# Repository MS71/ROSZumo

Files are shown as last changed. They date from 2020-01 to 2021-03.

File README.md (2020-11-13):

# ROSZumo
"second" Small robot based on ESP32 + ROS + ZUMO 32u4 base

Components:
* ZUMO32U4 Base (I2C Slave, Bat ADC, Motor Encoder, PWM for Lidar Stepper, l3gd20h, lsm303d, Line Sonsor, ...)
* ESP32CAM
* ESP32 WRoverwith CAM and SDCard
* driver and connector for rotating LIDAR
* 12x STM VL53L1X TOF sensor
* optional rotating Lidar with PCF8475+ULN2003 Stepper motor
* BNO055 Orientation Sensor
* STM32G081 uC
* connector for orange PI Zero H5
* connector for RPI SPI Display
* NIMH charger with front contacts
* SPI flash
* I2C level shifter
* I2C bus connector
* SPI bus connector
* low power design (shutdown and wakeup)
* optional Stereo/Quad SPI Camera

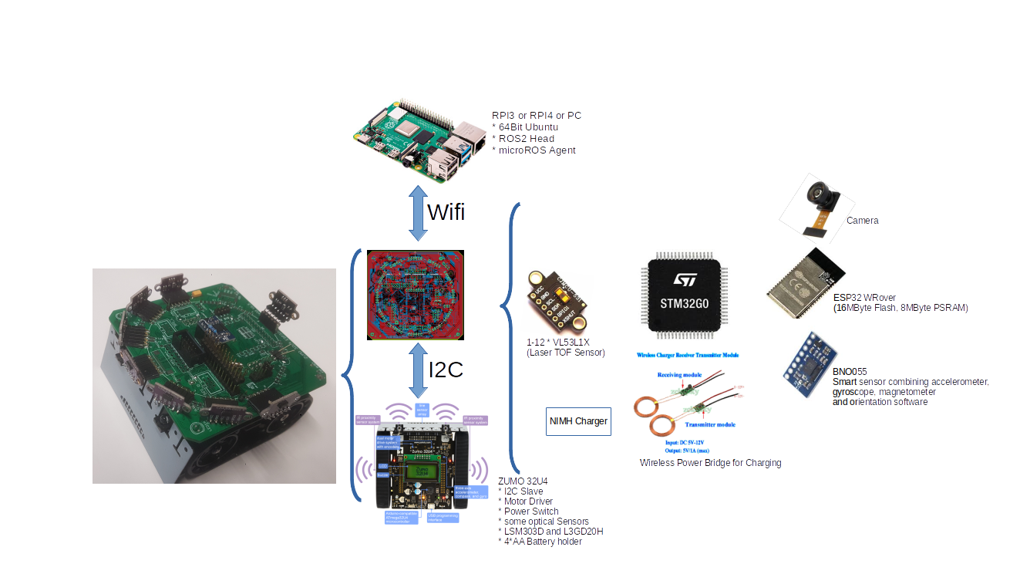
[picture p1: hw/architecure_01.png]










My Current Setup:
* Zumo AVR 32U4 
  * I2C slave
  * motor driver
  * bridge to all Zumo sensors (line sensor, beeper, IMU, ...)
  * battery pack 4xAA
  
* STM32G081
  * I2C slave
  * GPIO extender (e.g. for VL53L1X resets)
  * RPI LCD display driver
  * Battery changer
  * RTC
  * low power managment
  
* front VL53L1X as I2C slave

* ESP32Cam
  * I2C master
  * Camera
  * ROS2 Node
  * OTA firmware update
  
* external Linux PC or RPI3/4 as ROS2 master

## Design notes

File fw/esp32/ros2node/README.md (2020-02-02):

# ESP32 Camera Demo

Code provided in this repository gets the image from camera and prints it out as ASCII art to the serial port.

## Function
+ support OV2640 to output JPEG format .
+ support OV2640 and OV7725 to output grayscale format.
+ support QR recognize.

## Components

To make this code work, you need the following components:

* This repository. It contains submodules, so make sure you clone it with `--recursive` option. If you have already cloned it without `--recursive`, run `git submodule update --init`.
* [ESP32](https://espressif.com/en/products/hardware/esp32/overview) module
* Camera module
* PC with [esp-idf](https://github.com/espressif/esp-idf)

See the following sections for more details.

### Camera

This example has been tested with OV7725 and ov2640 camera modules. Use it, if this is your first exposure to interfacing a microcontroller with a camera.

Other OV7xxx series should work as well, with some changes to camera configuration code. OV5xxx can work too, but it is advisable to choose the ones which support RGB or YUV 8-bit wide output bus. The ones which only output 10-bit raw data may be a bit harder to work with. Also choose the camera which can output a scaled down (QVGA or VGA) image. Use of larger frame buffers will require external SPI RAM.

### Ai-Thinker CAM board

Ai-Thinker Launch a camera board.This board contain camera interface,TF card and ESP32 with psram.It is very a samll module.The size of the board is 40mm * 26mm * 4mm.You can plug the camera in the board.We will sell this board in our [taobao](https://shop72165205.taobao.com/?spm=a230r.7195193.1997079397.26.Z8Ck3C).

Aithinker camera board
Aithinker camera board front
Aithinker camera board qr recognize
Also,if you have an ESP-WROVER-KIT,you can try this demo.

## Quick Start

If you have your components ready, follow this section to [connect](#connect) the camera to ESP32 module, [flash](#flash) application to the ESP32 and finally [shoot](#shoot) and display the image.

## Connect

Specific pins used in this example to connect ESP32 and camera are shown in table below. Pinout can be adjusted to some extent in software. Table below provides two options of pin mapping (last two columns).

| Interface | Camera Pin | Pin Mapping for ESP32 DevKitJ | Ai-Thinker CAM board |
| :--- | :---: | :---: | :---: |
| SCCB Clock | SIOC | IO27 | IO27 |
| SCCB Data | SIOD | IO26 | IO26 |
| System Clock | XCLK | IO21 | IO0 |
| Vertical Sync | VSYNC | IO25 | IO25 |
| Horizontal Reference | HREF | IO23 | IO23 |
| Pixel Clock | PCLK | IO22 | IO22 |
| Pixel Data Bit 0 | D2 | IO4 | IO5 |
| Pixel Data Bit 1 | D3 | IO5 | IO18 |
| Pixel Data Bit 2 | D4 | IO18 | IO19 |
| Pixel Data Bit 3 | D5 | IO19 | IO21 |
| Pixel Data Bit 4 | D6 | IO36 | IO36 |
| Pixel Data Bit 5 | D7 | IO39 | IO39 |
| Pixel Data Bit 6 | D8 | IO34 | IO34 |
| Pixel Data Bit 7 | D9 | IO35 | IO35 |
| Camera Reset | RESET | IO2 | 3.3V |
| Camera Power Down | PWDN | *see Note 1* | GND |
| Power Supply 3.3V | 3V3 | 3V3 | IO32 |
| Ground | GND | GND | GND |

Notes:

1. **Camera pin** column refers to pinout on OV7725 camera module
2. **Camera Power Down** pin does not need to be connected to ESP32 GPIO. Instead it may be pulled down to ground with 10 kOhm resistor.

### Flash

Clone the code provided in this repository to your PC, compile with the latest [esp-idf](https://github.com/espressif/esp-idf) installed from GitHub and download to the module.

If all h/w components are connected properly you are likely to see the following message during download:

```
Krzysztof@tdk-kmb-op780 MSYS /esp/esp32-cam-demo
$ make flash
Flashing binaries to serial port com18 (app at offset 0x10000)...
esptool.py v2.0-dev
Connecting...

A fatal error occurred: Failed to connect to ESP32: Timed out waiting for packet header
make: *** [C:/msys32/esp-idf/components/esptool_py/Makefile.projbuild:48: flash] Error 2
```
This is due to a pullup on the camera reset line. It is stronger than the internal pull-down on `GPIO2` of the ESP32, so the chip cannot go into programming mode.

There are couple of options how to resolve this issue:

* If you are using ESP-WROVER V1 then connect GPIO2 to GND while flashing.
* Power down the camera module by removing it from the socket (ESP-WROVER V1) or by uplugging 3.3V wire.
* Map Camera Reset line to another GPIO pin on ESP32, for instance `GPIO15`.

### Shoot

Once module is loaded with code, open a serial terminal.

Camera demo application will first configure XCLK output that is timing operation of the camera chip.

If you set the pin of the xclk as GPIO0,the clock will be output by I2S1.The wave of clock is the best.
```
I (71) I2S: DMA Malloc info, datalen=blocksize=256, dma_buf_count=8
I (71) I2S: PLL_D2: Req RATE: 78125, real rate: 78125.000, BITS: 16, CLKM: 8, BCK: 8, MCLK: 20000000.000, SCLK: 2500000.000000, diva: 64, divb: 0
I (81) camera_xclk: PIN_CTRL before:3ff
I (81) camera_xclk: PIN_CTRL after:7fff
```
If you set the pin of the xclk as other GPIO,the clock will be output by ledc.
```
D (1527) camera: Enabling XCLK output
I (1527) ledc: LEDC_PWM CHANNEL 0|GPIO 21|Duty 0004|Time 0
```
This clock is also timing output of pixel data on camera output interface - see I2S and DMA described below.

Then [SCCB](http://www.ovt.com/download_document.php?type=document&DID=63) interface is set up:

```
D (1527) camera: Initializing SSCB
I (1537) gpio: GPIO[26]| InputEn: 0| OutputEn: 1| OpenDrain: 0| Pullup: 0| Pulldown: 0| Intr:0
I (1537) gpio: GPIO[27]| InputEn: 0| OutputEn: 1| OpenDrain: 0| Pullup: 0| Pulldown: 0| Intr:0
I (1547) gpio: GPIO[26]| InputEn: 1| OutputEn: 0| OpenDrain: 0| Pullup: 1| Pulldown: 0| Intr:0
I (1557) gpio: GPIO[27]| InputEn: 1| OutputEn: 0| OpenDrain: 0| Pullup: 1| Pulldown: 0| Intr:0
```

In next step the communication with camera should be established. ESP will retrieve camera's address and signature.

```
D (1567) camera: Resetting camera
D (1587) camera: Searching for camera address
D (1587) camera: Detected camera at address=0x21
D (1587) camera: Camera PID=0x77 VER=0x21 MIDL=0x7f MIDH=0xa2
```

If communication fails, the following message is shown:

```
E (1076) camera: Camera address not found
E (1076) camera_demo: Camera init failed with error = 131073
```

If communication with camera module is established, ESP will reset the camera sensor and reserve memory for video frame buffer:

```
D (1587) camera: Doing SW reset of sensor
D (1647) camera: Setting frame size at 320x240
D (1677) camera: Allocating frame buffer (320x240, 76800 bytes)
```

Image from camera is retrieved using I2S communication for all eight pixel bits at once and saved in memory line by line. Log below shows completion of initialization steps for I2S and DMA:

```
D (1677) camera: Initializing I2S and DMA
I (1677) gpio: GPIO[35]| InputEn: 1| OutputEn: 0| OpenDrain: 0| Pullup: 0| Pulldown: 0| Intr:0
I (1677) gpio: GPIO[34]| InputEn: 1| OutputEn: 0| OpenDrain: 0| Pullup: 0| Pulldown: 0| Intr:0
I (1687) gpio: GPIO[39]| InputEn: 1| OutputEn: 0| OpenDrain: 0| Pullup: 0| Pulldown: 0| Intr:0
I (1697) gpio: GPIO[36]| InputEn: 1| OutputEn: 0| OpenDrain: 0| Pullup: 0| Pulldown: 0| Intr:0
I (1707) gpio: GPIO[19]| InputEn: 1| OutputEn: 0| OpenDrain: 0| Pullup: 0| Pulldown: 0| Intr:0
I (1717) gpio: GPIO[18]| InputEn: 1| OutputEn: 0| OpenDrain: 0| Pullup: 0| Pulldown: 0| Intr:0
I (1727) gpio: GPIO[5]| InputEn: 1| OutputEn: 0| OpenDrain: 0| Pullup: 0| Pulldown: 0| Intr:0
I (1737) gpio: GPIO[4]| InputEn: 1| OutputEn: 0| OpenDrain: 0| Pullup: 0| Pulldown: 0| Intr:0
I (1747) gpio: GPIO[25]| InputEn: 1| OutputEn: 0| OpenDrain: 0| Pullup: 0| Pulldown: 0| Intr:0
I (1757) gpio: GPIO[23]| InputEn: 1| OutputEn: 0| OpenDrain: 0| Pullup: 0| Pulldown: 0| Intr:0
I (1767) gpio: GPIO[22]| InputEn: 1| OutputEn: 0| OpenDrain: 0| Pullup: 0| Pulldown: 0| Intr:0
D (1777) intr_alloc: Connected src 32 to int 3 (cpu 0)
D (1777) camera: Allocating DMA buffer #0, size=1280
D (1787) camera: Allocating DMA buffer #1, size=1280
D (1817) camera: Init done
```

## How it Works

### Software

The core of camera software is contained in `camera` folder and consists of the following files.

* [camera.c](components/camera/camera.c) and [include/camera.h](components/camera/include/camera.h) - main file responsible for configuration of ESP32's GPIO, clock, I2S and DMA to interface with camera module. Once interface is established, it perfroms camera configuration to then retrieve image and save it in ESP32 memory. Access to camera is executed using lower level routines in the following files.

* [ov7725.c](components/camera/ov7725.c), [ov7725.h](components/camera/ov7725.h), [ov7725_regs.h](components/camera/ov7725_regs.h) and [sensor.h](components/camera/sensor.h) - definition of registers of OV7725 to configure camera funcinality. Functions to set register groups to reset camera to default configuration and configure specific functionality like resolution or pixel format. Setting he registers is performed by lower level function in files below.

* [sccb.c](components/camera/sccb.c) and [sccb.h](components/camera/sccb.h) - implementation of [Serial Camera Control Bus (SCCB)](http://www.ovt.com/download_document.php?type=document&DID=63) protocol to set camera registers.

* [twi.c](components/camera/twi.c) and [twi.h](components/camera/twi.h) - implementation of software I2C routines used by SCCB protocol.

* [wiring.c](components/camera/wiring.c) and [wiring.h](components/camera/wiring.h) - the lowest level routines to set GPIO pin mode, set GPIO pin level and delay program execution by required number of ms.

* [component.mk](components/camera/component.mk) - file used by C `make` command to access component during compilation.

* [Kconfig.projbuild](components/camera/Kconfig.projbuild) - file used by `make menuconfig` that provides menu option to switch camera test pattern on / off.

All above are called _esp-idf component_ and placed in `components` folder. Esp-idf framework provides `components` folder as a standard place to add modular functionality to a project.

Application starts and the top level control is executed from [app_main.c](main/app_main.c) file located in [main](main) folder.

## Troubleshooting

If you have issues to get the live image right, enable test pattern and see what is retrieved.

To do so, run `make menuconfig`, open `Example Configuration` menu option and check `[ ] Enable test pattern on camera output`.

Optionally change the following define in file `camera.c`:

```
# define ENABLE_TEST_PATTERN CONFIG_ENABLE_TEST_PATTERN
```

Camera sensor will then output test pattern instead of live image.

```
D (5692) camera: Waiting for positive edge on VSYNC
D (5722) camera: Got VSYNC
D (5722) camera: Waiting for frame
D (5752) camera: Frame done
D (5752) camera_demo: Done
|@@@@@@@@@@@@@@@@@@@@@%%%%%%%%%########## +++++++++==========-:::::::::          |
|@@@@@@@@@@@@@@@@@@@@@%%%%%%%%%########## +++++++++==========-:::::::::          |
|@@@@@@@@@@@@@@@@@@@@@%%%%%%%%%########## +++++++++==========-:::::::::          |
|@@@@@@@@@@@@@@@@@@@@@%%%%%%%%%########## +++++++++==========-:::::::::          |
|@@@@@@@@@@@@@@@@@@@@@%%%%%%%%%########## +++++++++==========-:::::::::          |
|@@@@@@@@@@@@@@@@@@@@@%%%%%%%%%########## +++++++++==========-:::::::::          |
|@@@@@@@@@@@@@@@@@@@@@%%%%%%%%%########## +++++++++==========-:::::::::          |
|@@@@@@@@@@@@@@@@@@@@@%%%%%%%%%########## +++++++++==========-:::::::::          |
```

O
nce test pattern is enabled, application will calculate standard variance of what is retrieved by ESP32 against pattern generated by the camera module. If there is noise on the lines or some pixels lines not connected or shortcut, this should be reported below displayed image. 

```
Frames / mismatch : 4630 / 70 (1%), (6531449)
```
The value in brackets with % sign provides number of frames that differ from the test pattern. See code inline comments for more information on this functionality.

## QR Recognition
ESP32_CAMERA_QR contain QR library.
To do so, run `make menuconfig`, open `ESP32 Camera Demo Configuration` menu option and check QR recognize Support.
Then change the following define in file `app_main.c`:
```
#define CAMERA_PIXEL_FORMAT CAMERA_PF_GRAYSCALE
#define CAMERA_FRAME_SIZE CAMERA_FS_QVGA
```
note: 
+ If you want to recognize QR,the CAMERA_PIXEL_FORMAT must be seted as CAMERA_PF_GRAYSCALE.
+ The size of photo can't be over VGA.Or the ram may be  oversize.

QR recognition

## Next Steps

We are planning to test and compare images captured using:

+ Planning to transplant [openmv](https://github.com/openmv/openmv)
+ Planing to increase the framerate.

## Help
+ Hope developers to provide the driver of OV2640 cif mode.
+ We are going to add other camera.if you have the driver of new camera,please tell to me.

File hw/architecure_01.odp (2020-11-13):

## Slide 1

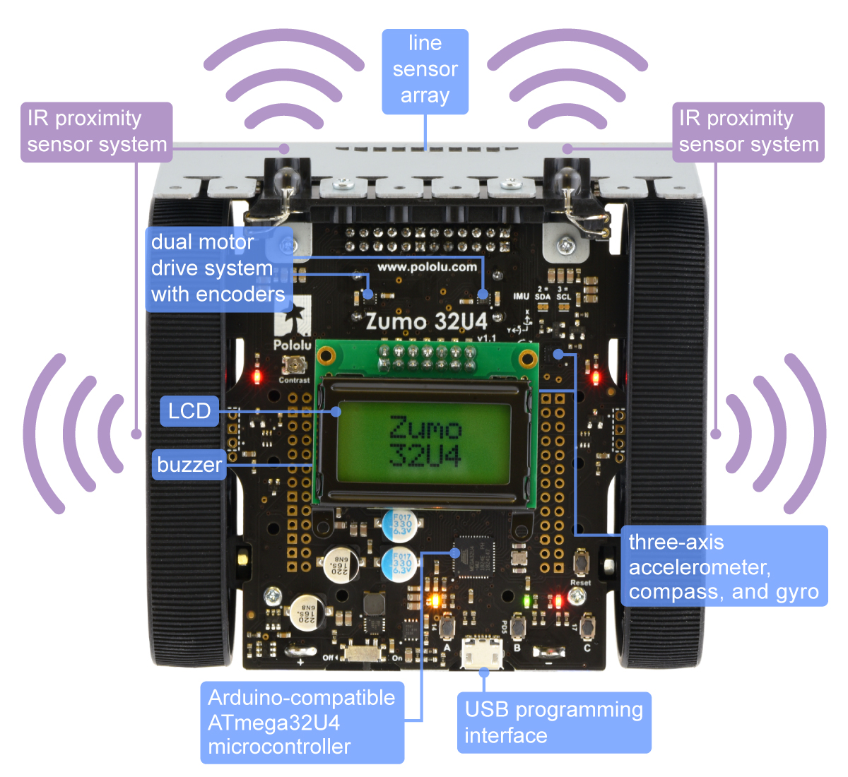
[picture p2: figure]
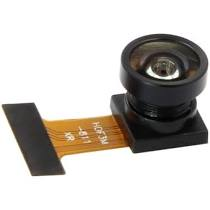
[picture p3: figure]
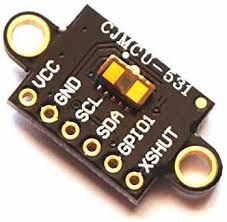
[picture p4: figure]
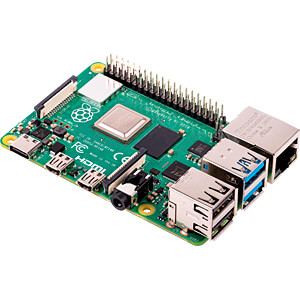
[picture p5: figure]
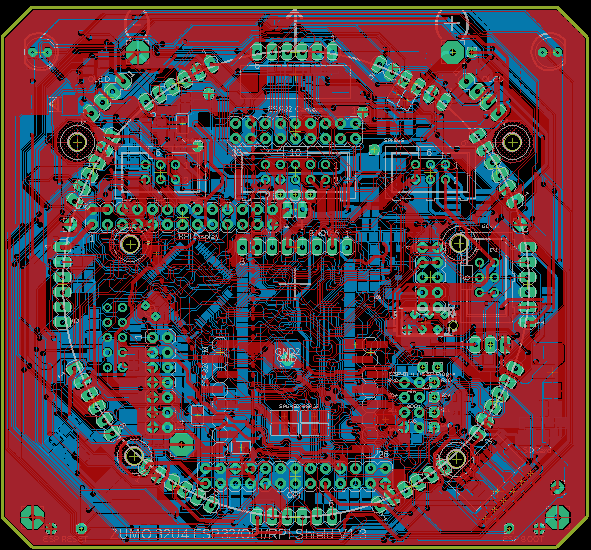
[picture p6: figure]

RPI3 or RPI4 or PC

* 64Bit Ubuntu

* ROS2 Head

Wifi

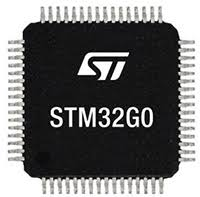
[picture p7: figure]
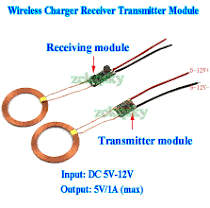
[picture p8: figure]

Wireless Power Bridge for Charging

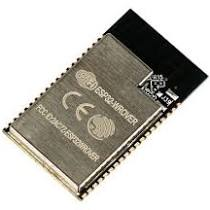
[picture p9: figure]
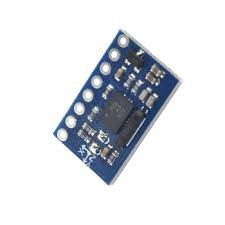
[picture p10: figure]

Camera

ESP32 WRover

(16MByte Flash, 8MByte PSRAM)

I2C

1-12 * VL53L1X

(Laser TOF Sensor)

1-12 * VL53L1X

(Laser TOF Sensor)

BNO055

Smart sensor combining accelerometer,

gyroscope, magnetometer and orientation software

ZUMO 32U4

* I2C Slave

* Motor Driver

* Power Switch

* some optical Sensors

* LSM303D and L3GD20H

* 4*AA Battery holder

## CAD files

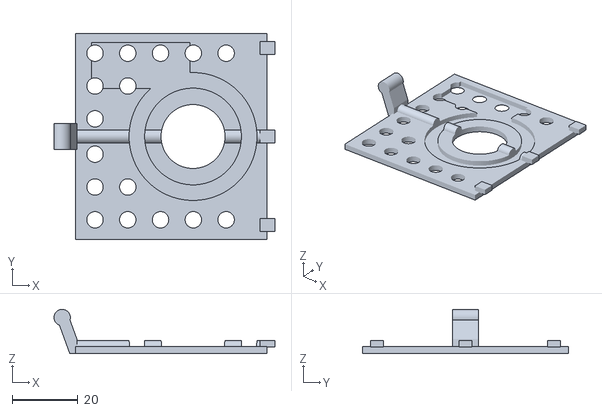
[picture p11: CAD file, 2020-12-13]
3dparts/zumo_bat_cover.stl
67.4 x 62.8 x 13.5

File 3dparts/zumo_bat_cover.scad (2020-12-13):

$fn=100;
h=2.1;
coil_h=1.75;
coil_d1=29.5;
coil_d2=39;
b=58.4;
l=62.8;
cooling_holes=1;

difference()
{
    union()
    {
        linear_extrude(h) square([b,l],true);
        translate([-b/2,0,2]) rotate([0,90,0]) linear_extrude(b) circle(d=4);
    }
    union()
    {
        translate([(b-coil_d2)/2-3,0,h-coil_h]) difference()
        {
          linear_extrude(coil_h+5) circle(d=coil_d2);
          linear_extrude(coil_h+5) circle(d=coil_d1);
        }
        if( cooling_holes )
        {
            translate([(b-coil_d2)/2-3,0,0]) linear_extrude(coil_h+5) circle(d=coil_d1-10);
            
            xxx=5;
            yyy=10;
            translate([-b/2+6,-l/2+6+2*yyy,0]) linear_extrude(coil_h+1) circle(d=xxx);
            translate([-b/2+6,-l/2+6+yyy,0]) linear_extrude(coil_h+1) circle(d=xxx);
            translate([-b/2+6+1*yyy,-l/2+6+yyy,0]) linear_extrude(coil_h+1) circle(d=xxx);
            translate([-b/2+6,-l/2+6,0]) linear_extrude(coil_h+1) circle(d=xxx);
            translate([-b/2+6+1*yyy,-l/2+6,0]) linear_extrude(coil_h+1) circle(d=xxx);
            translate([-b/2+6+2*yyy,-l/2+6,0]) linear_extrude(coil_h+1) circle(d=xxx);
            translate([-b/2+6+3*yyy,-l/2+6,0]) linear_extrude(coil_h+1) circle(d=xxx);
            translate([-b/2+6+4*yyy,-l/2+6,0]) linear_extrude(coil_h+1) circle(d=xxx);

            translate([-b/2+6,l/2-6-2*yyy,0]) linear_extrude(coil_h+1) circle(d=xxx);
            translate([-b/2+6,l/2-6-yyy,0]) linear_extrude(coil_h+1) circle(d=xxx);
            translate([-b/2+6+1*yyy,l/2-6-yyy,0]) linear_extrude(coil_h+1) circle(d=xxx);
            translate([-b/2+6,l/2-6,0]) linear_extrude(coil_h+1) circle(d=xxx);
            translate([-b/2+6+1*yyy,l/2-6,0]) linear_extrude(coil_h+1) circle(d=xxx);
            translate([-b/2+6+2*yyy,l/2-6,0]) linear_extrude(coil_h+1) circle(d=xxx);
            translate([-b/2+6+3*yyy,l/2-6,0]) linear_extrude(coil_h+1) circle(d=xxx);
            translate([-b/2+6+4*yyy,l/2-6,0]) linear_extrude(coil_h+1) circle(d=xxx);
        }
        translate([-b/2+20,l/4+7-1,h-coil_h]) linear_extrude(coil_h+1) square([30,14],true);
    }
}


translate([b/2-1,-27,0]) union()
{
    linear_extrude(4) square([2,4],true);
    translate([2,0,2]) linear_extrude(2) square([2+1,4],true);
}
translate([b/2-1,0,0]) union()
{
    linear_extrude(4) square([2,4],true);
    translate([2,0,2]) linear_extrude(2) square([2+1,4],true);
}
translate([b/2-1,+27,0]) union()
{
    linear_extrude(4) square([2,4],true);
    translate([2,0,2]) linear_extrude(2) square([2+1,4],true);
}

translate([-b/2-1-1.5/2,0,0]) union()
{
    difference()
    {
      //linear_extrude(9+2) square([3+1.5,8],true);
      translate([-0.5,0,0]) linear_extrude(9+2) square([3+1.5+1,8],true);
      translate([4.8,0,4]) rotate([0,-20,0]) linear_extrude(9+2) square([3+1.5,8],true);
      translate([-1.5,0,-2.3]) rotate([0,-20,0]) linear_extrude(9+2) square([3+1.5,8],true);
    }
    //translate([-1.5-1.5/2,4,9+1]) rotate([90,0,0]) linear_extrude(8) circle(d=3);
    translate([-1.5-1.5/2,4,9+1+1]) rotate([90,0,0]) linear_extrude(8) circle(d=5);
}

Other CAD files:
3dparts/zumo_docking.scad

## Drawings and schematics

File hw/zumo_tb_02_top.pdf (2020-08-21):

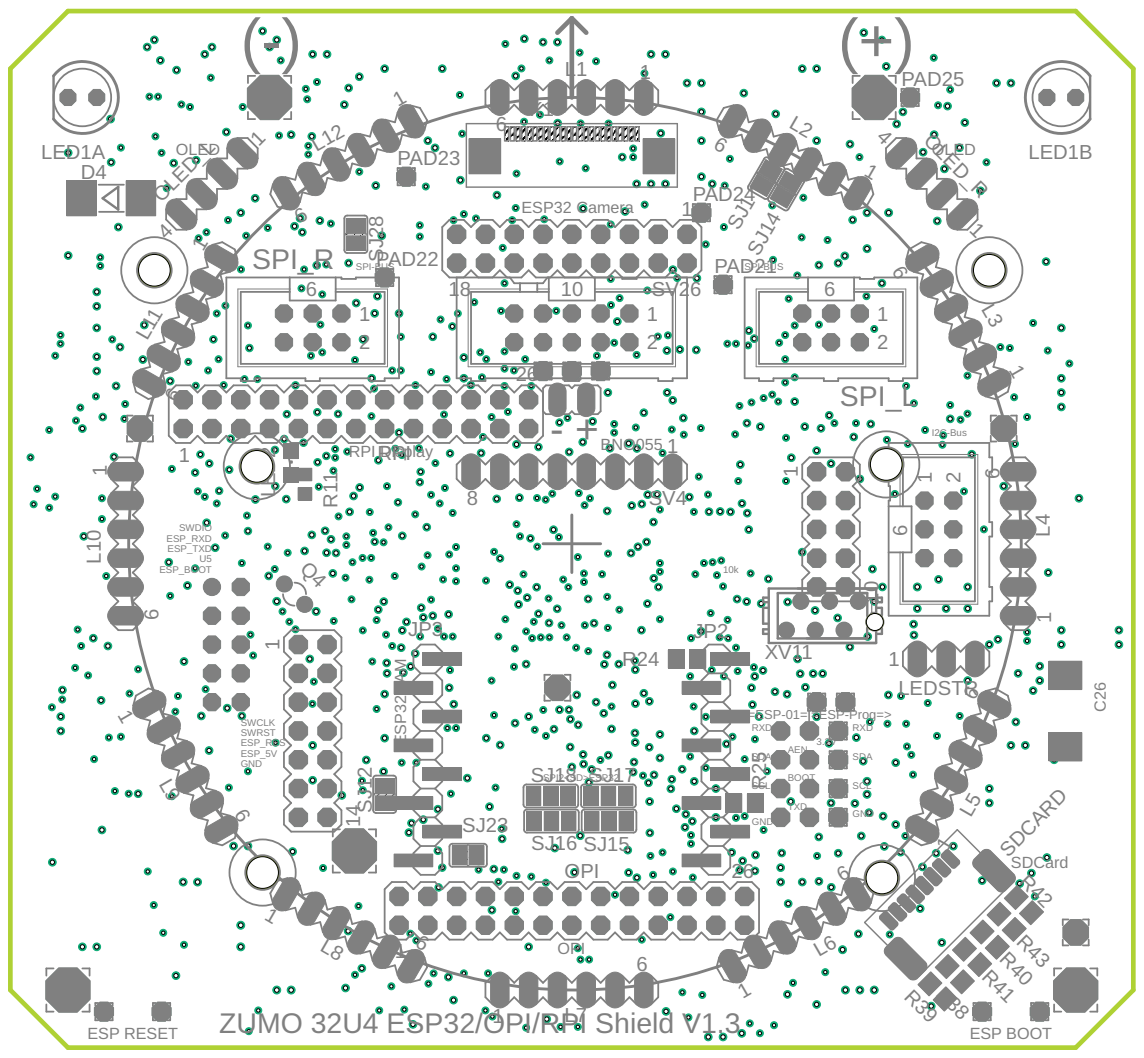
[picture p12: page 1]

ZUMO 32U4 ESP32/OPI/RPI Shield V1.3

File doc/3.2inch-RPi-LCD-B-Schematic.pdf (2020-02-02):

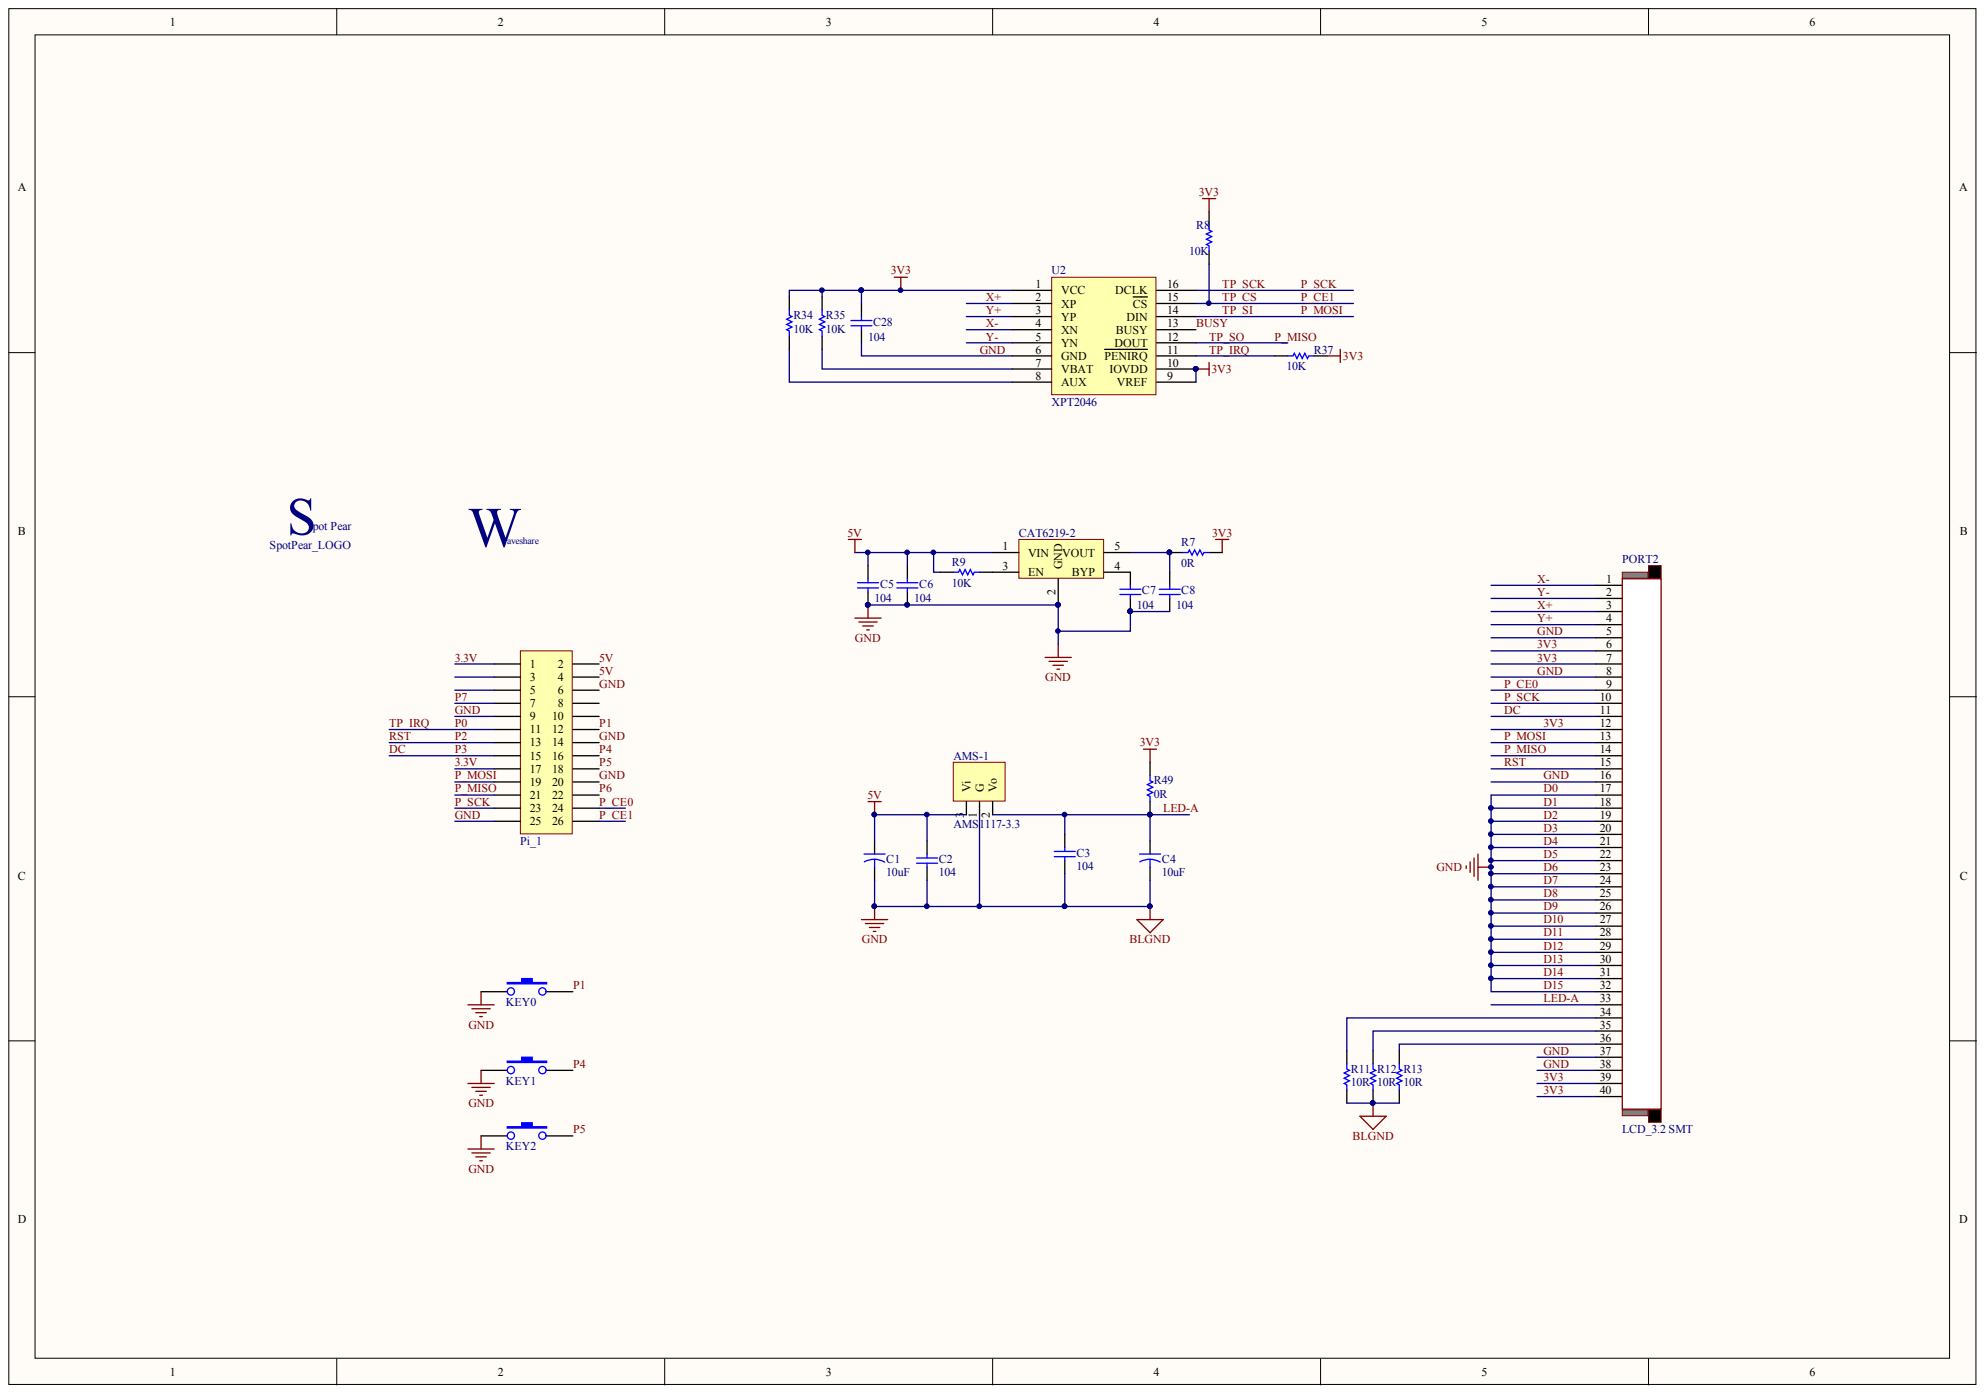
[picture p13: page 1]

D1 | 1 8
D2 | 1 9

D4 | 2 1
D5 | 2 2
D6 | 2 3
D7 | 2 4
D8 | 2 5
D9 | 2 6
D1 0 | 2 7
D1 1 | 2 8
D1 2 | 2 9
D1 3 | 3 0
D1 4 | 3 1
D1 5 | 3 2

3 5
3 6

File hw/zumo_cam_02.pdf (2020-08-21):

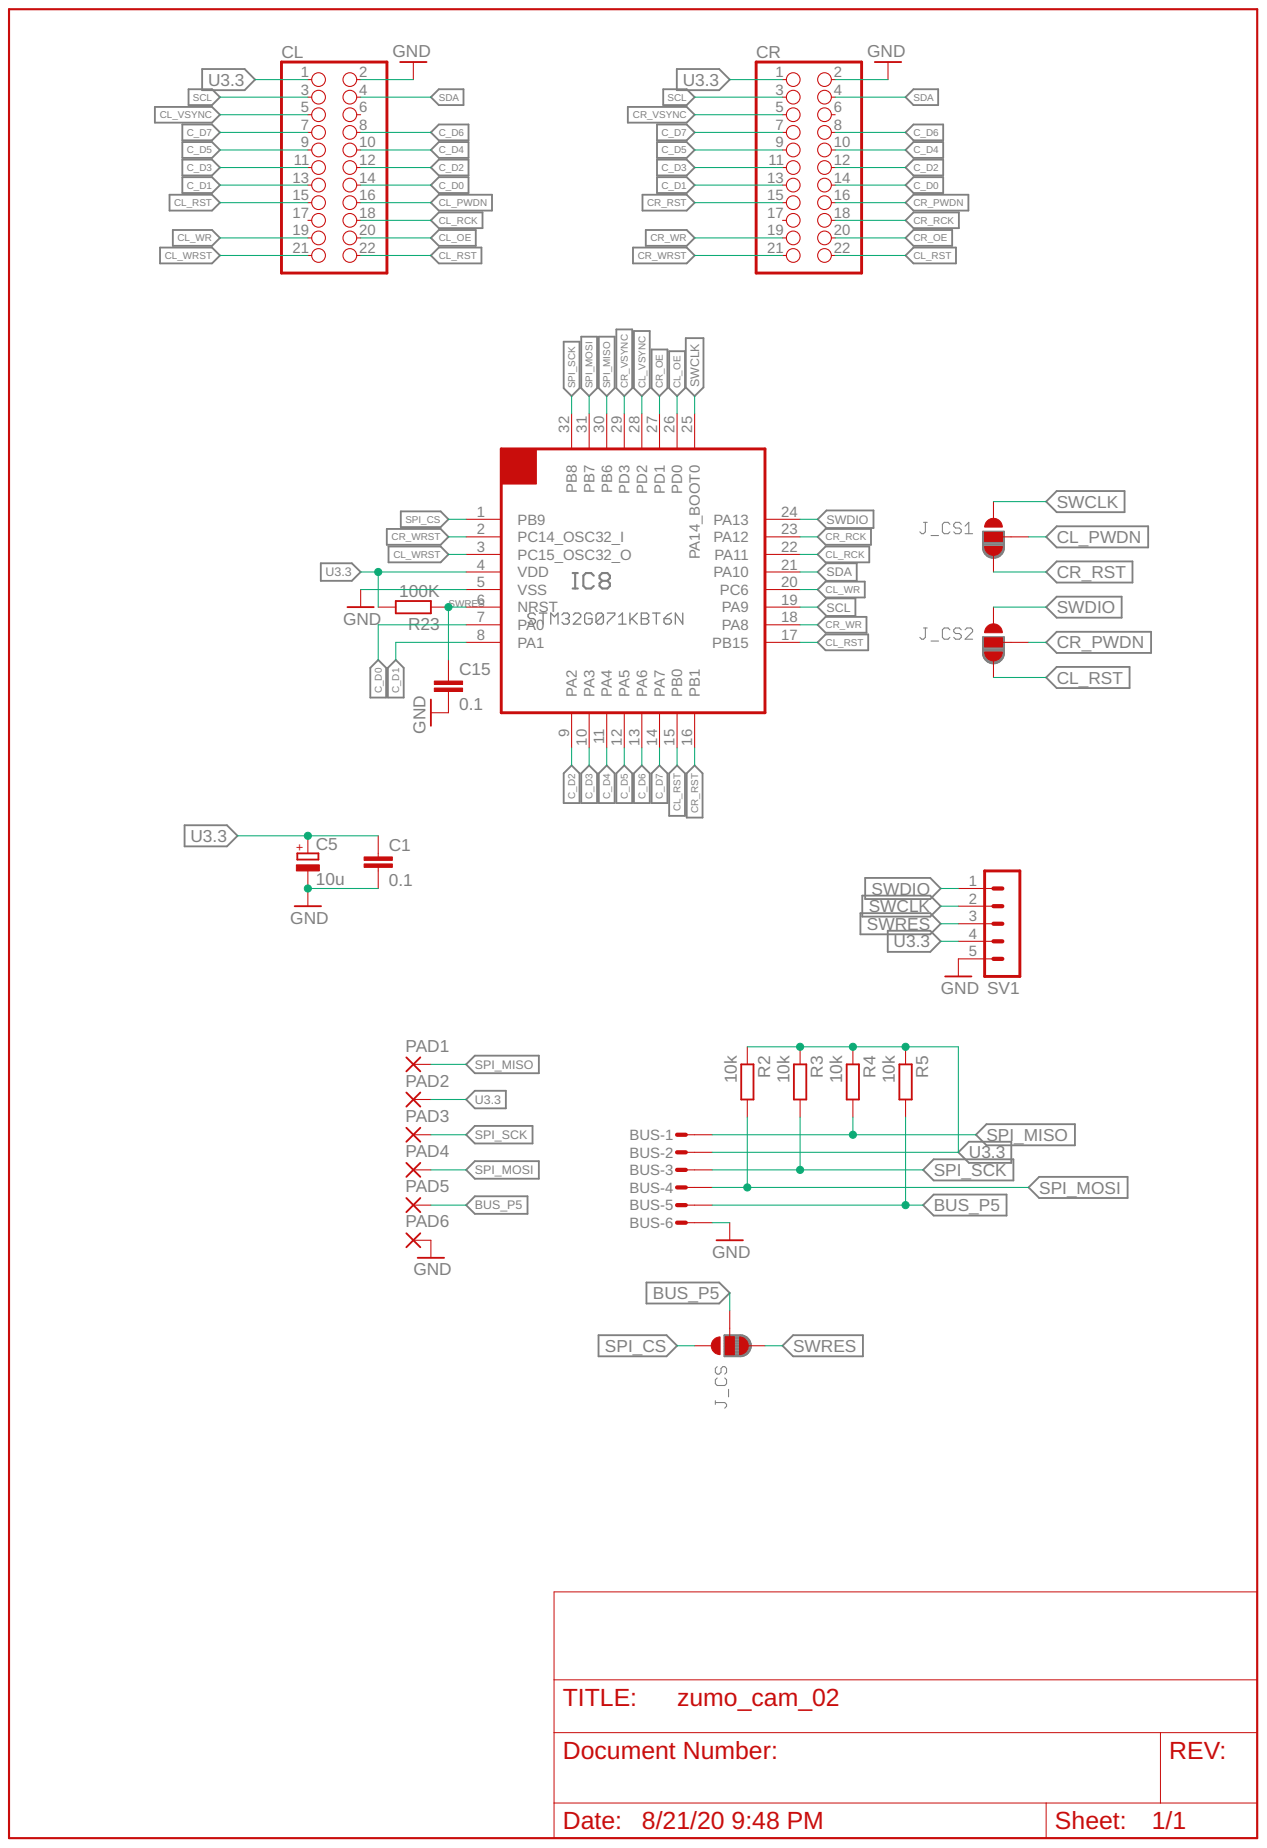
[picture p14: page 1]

Document Number: | REV:

Date: 8/21/20 9:48 PM | Sheet: 1/1

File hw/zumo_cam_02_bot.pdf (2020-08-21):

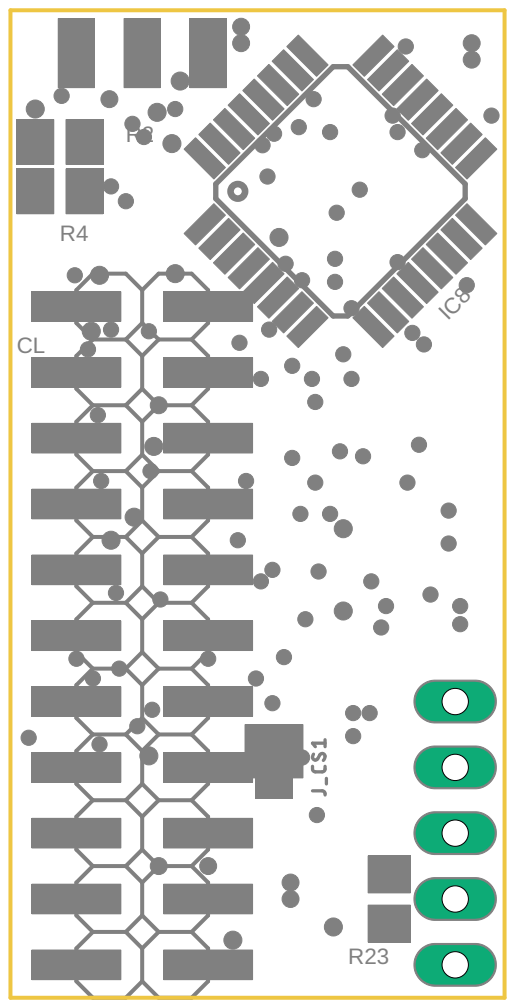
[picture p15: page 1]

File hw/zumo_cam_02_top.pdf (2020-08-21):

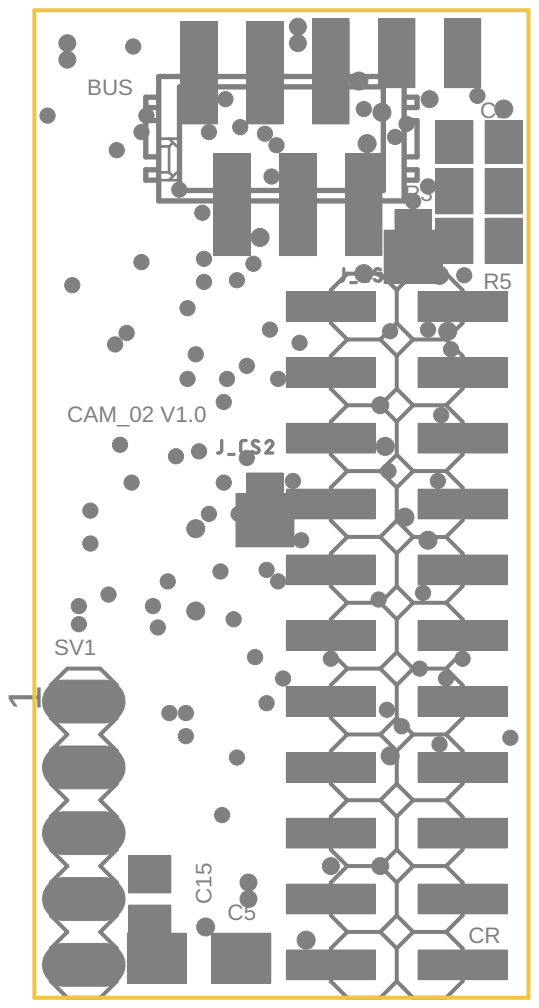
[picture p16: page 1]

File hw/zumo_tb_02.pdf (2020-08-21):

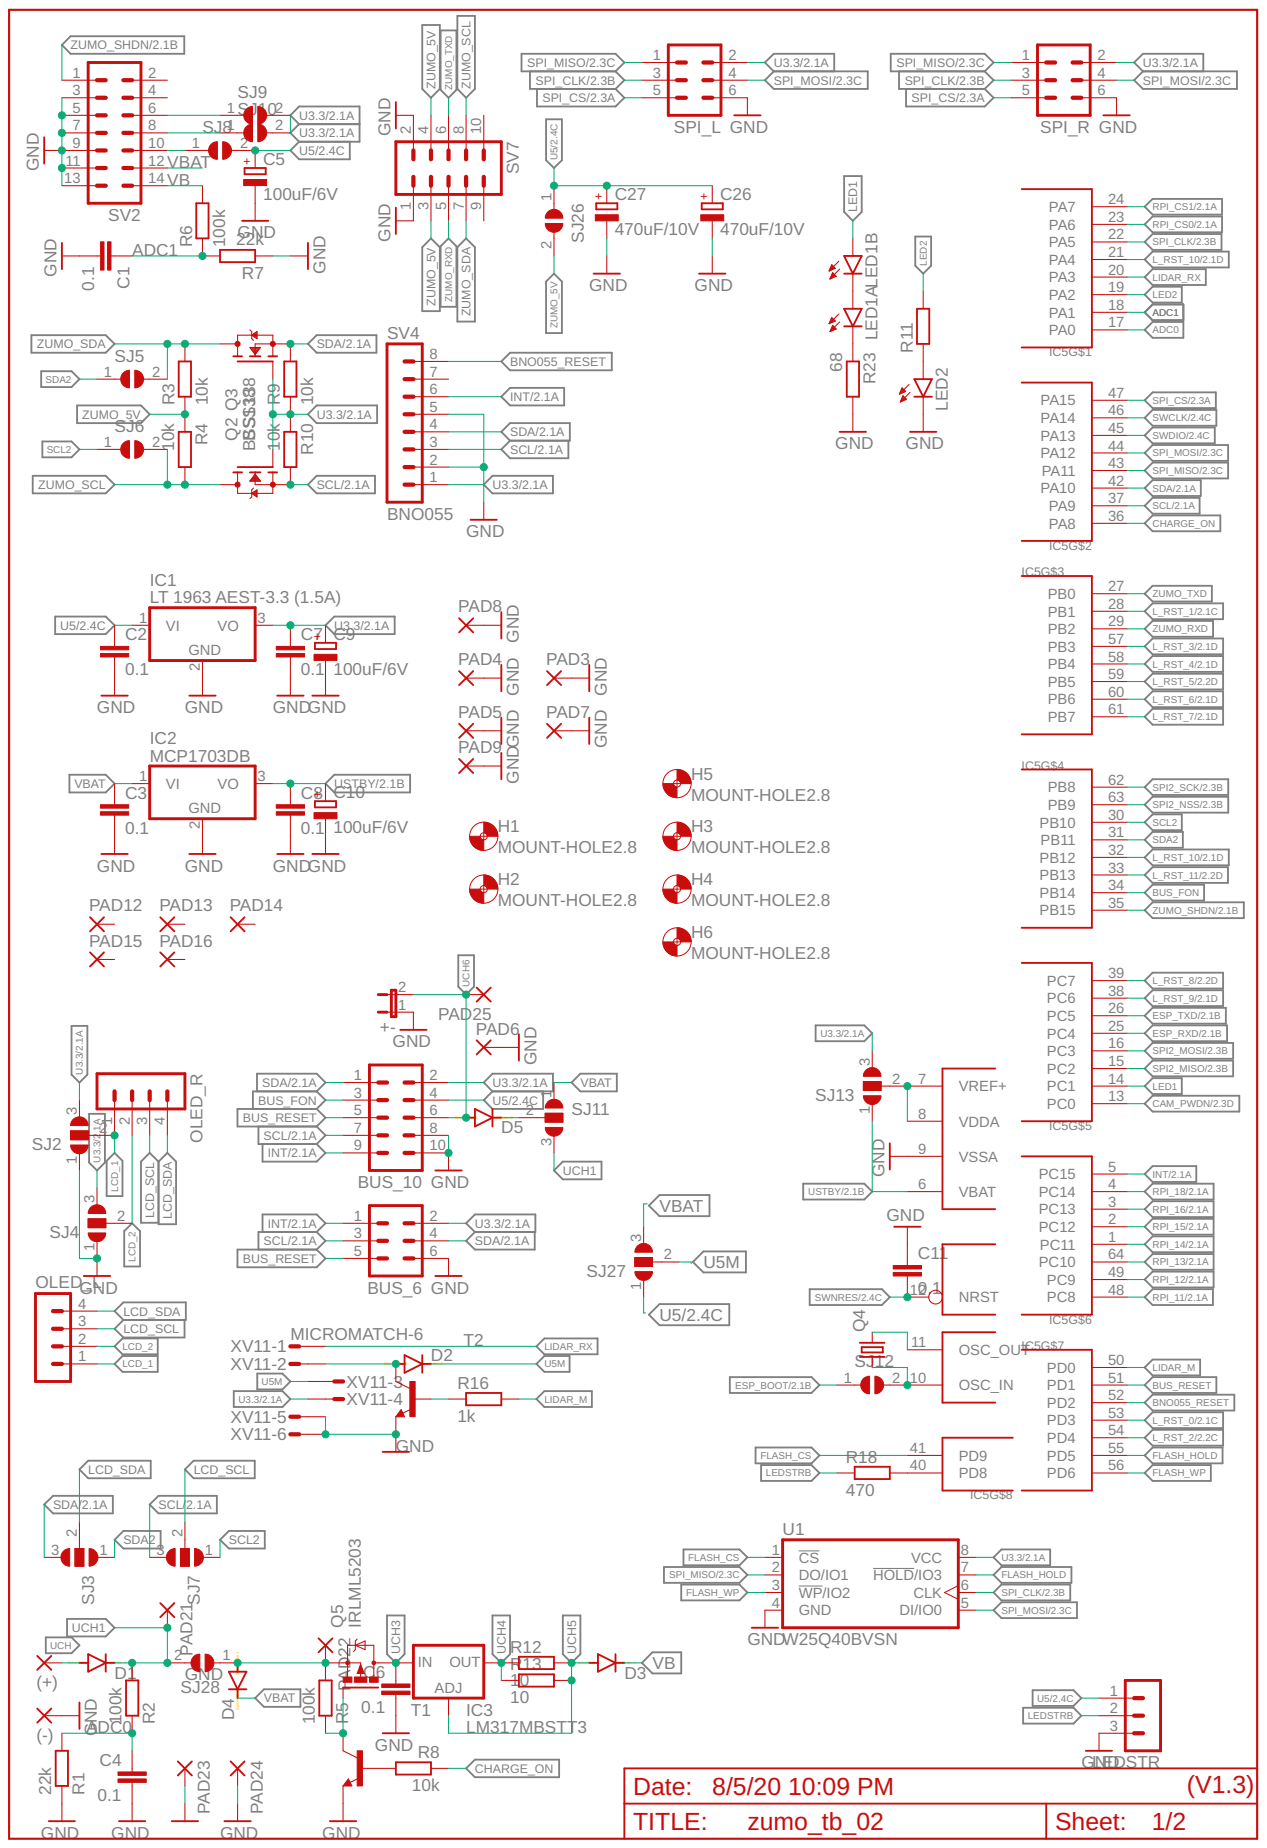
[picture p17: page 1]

11 | 12 VBAT
13 | 14 VB

INT/2.1A | U3.3/2.1A
SCL/2.1A | SDA/2.1A

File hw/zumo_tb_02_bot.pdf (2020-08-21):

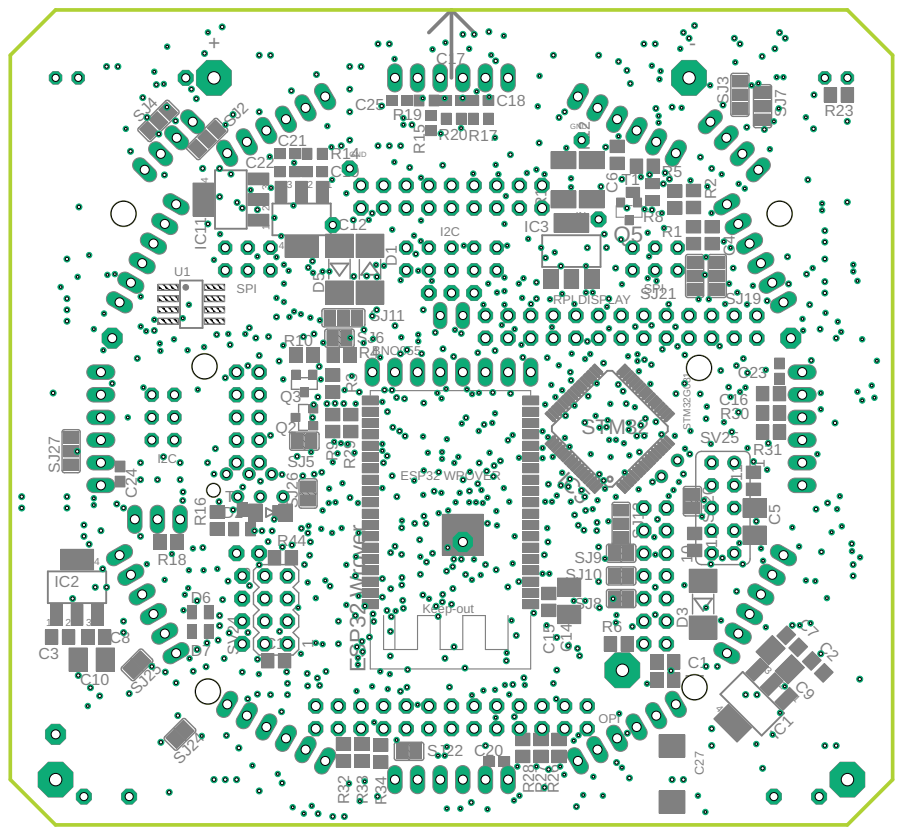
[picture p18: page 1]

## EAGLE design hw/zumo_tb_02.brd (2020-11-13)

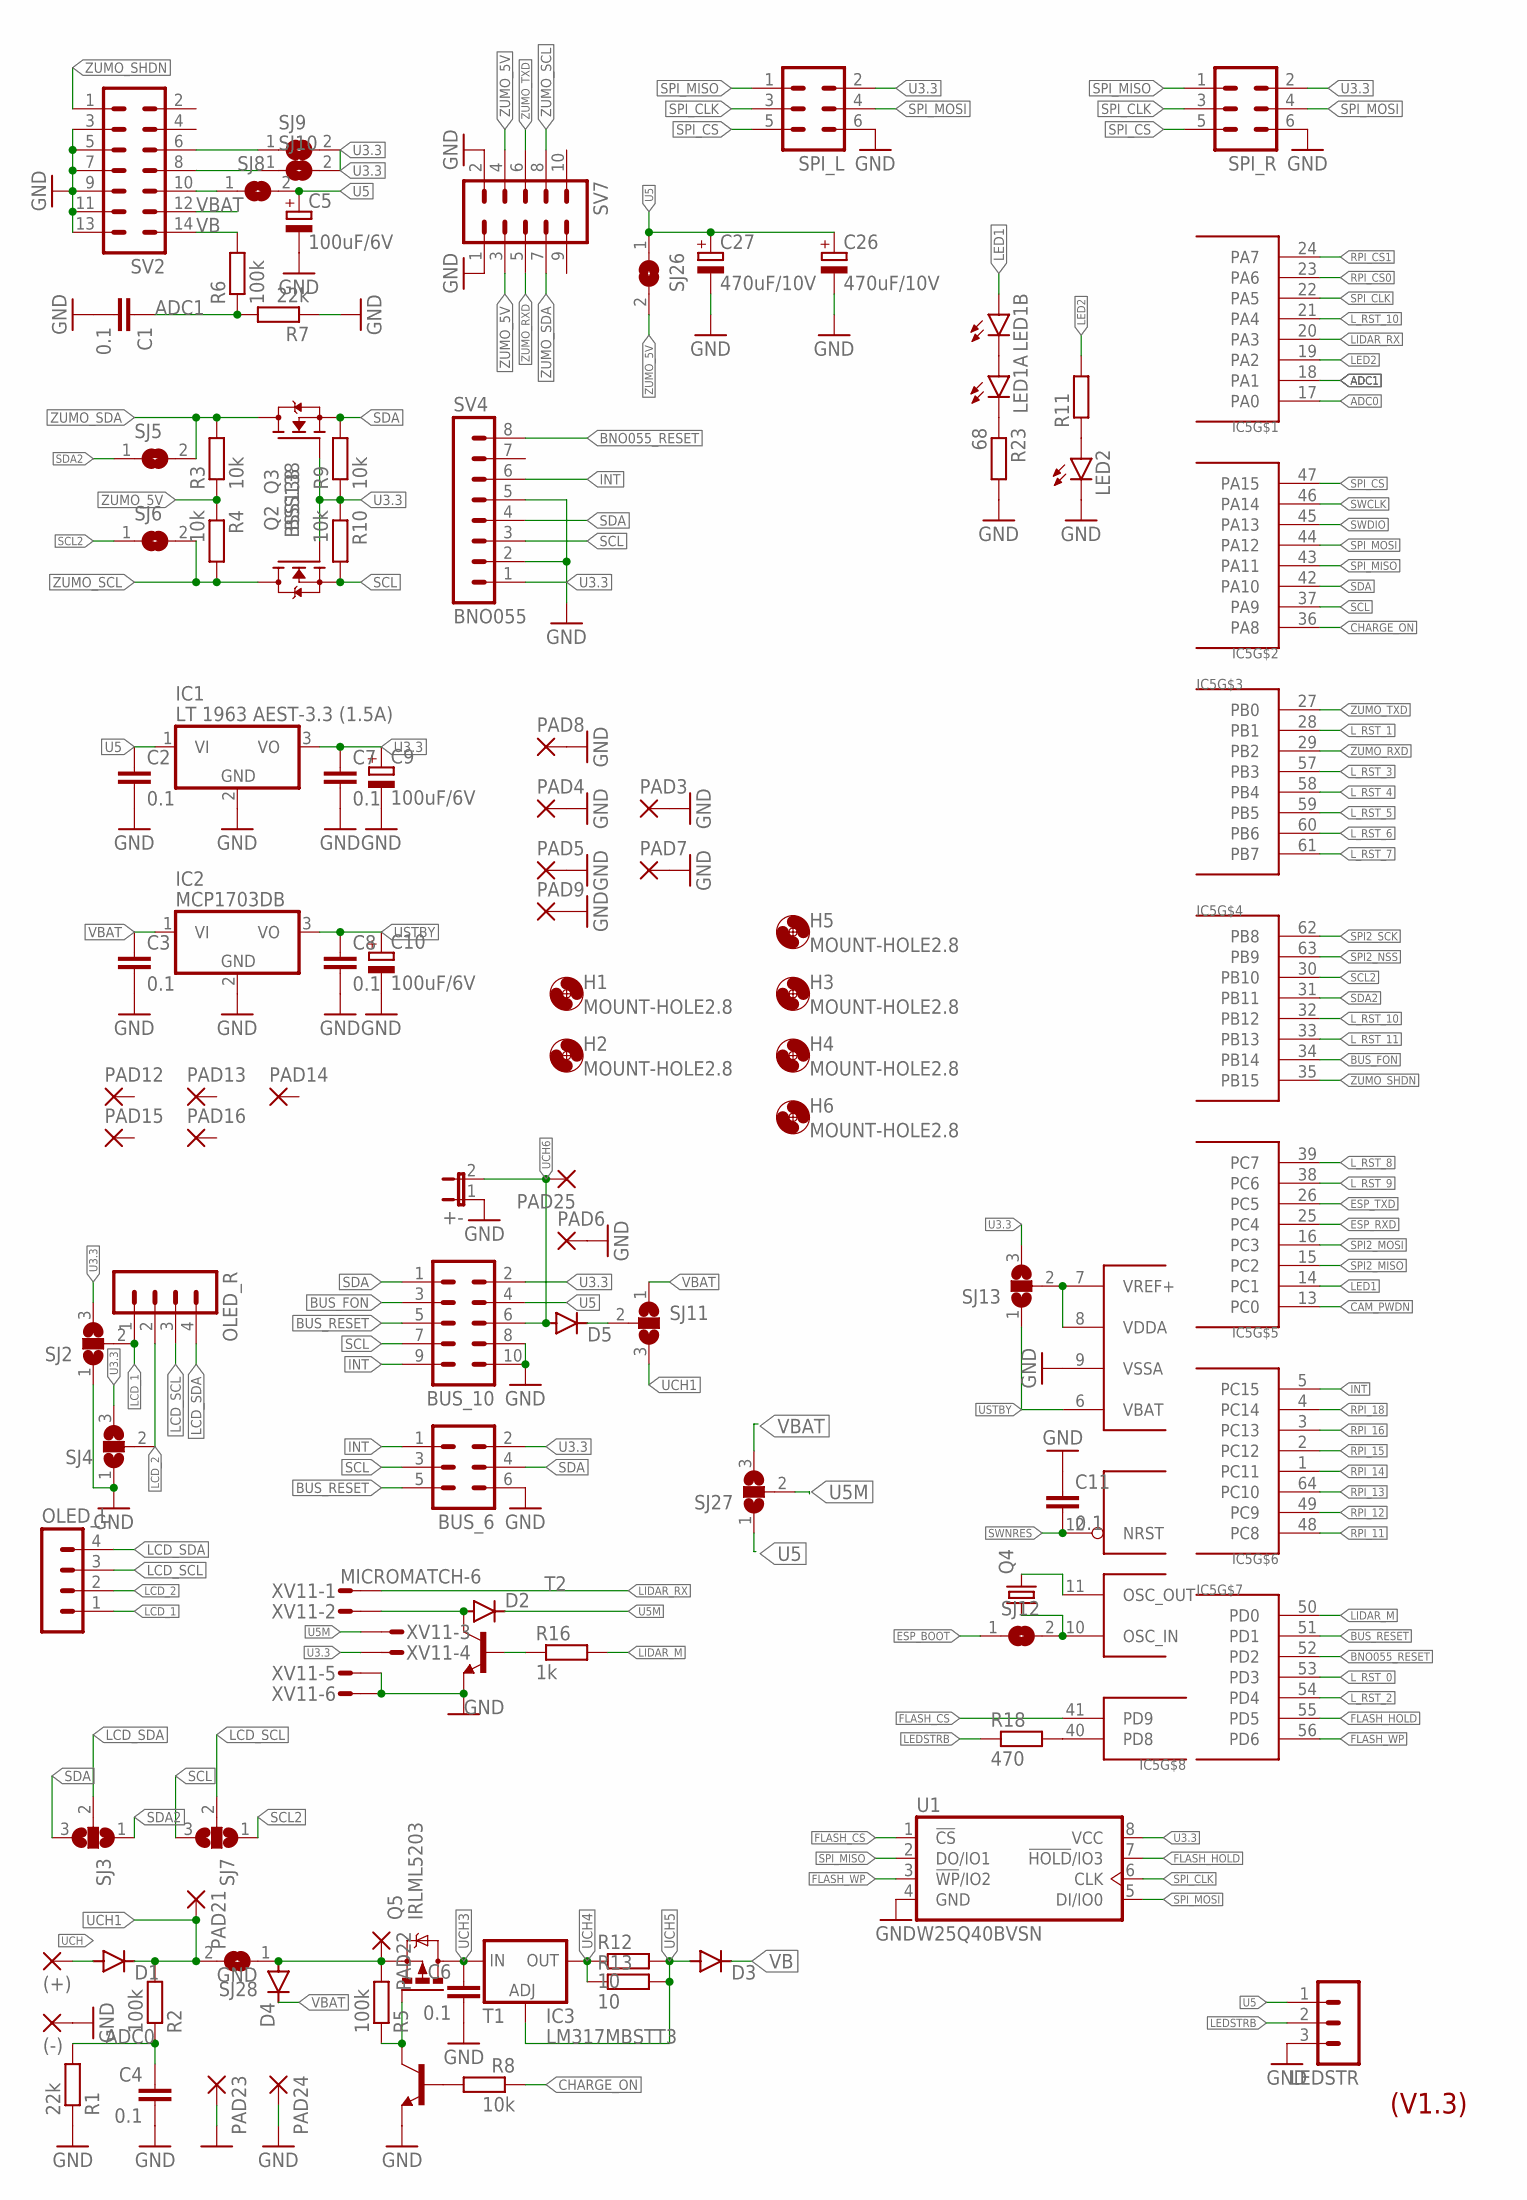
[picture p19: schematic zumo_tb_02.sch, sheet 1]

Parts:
(+): 3,81/1,4
(-): 3,81/1,4
+-: JP1E; JP1
BUS_6: ML6
BUS_10: ML10
C1, C2, C3, C4, C6, C7, C8, C11: 0.1; C0805
C5, C9, C10: 100uF/6V; B/3528-21R
C26, C27: 470uF/10V; SMC_D
D1, D3, D4, D5: DIODE-MELF-MLL41; MELF-MLL41
D2: DIODE-MINIMELF; MINIMELF
H1, H2, H3, H4, H5, H6: MOUNT-HOLE2.8; 2,8
IC1: LT 1963 AEST-3.3 (1.5A); SOT223
IC2: MCP1703DB; SOT223
IC3: LM317MBSTT3; SOT223
IC5: STM32G081RBT6; TQFP64
LED1A, LED1B: LED5MM
LED2: LEDCHIPLED_0805; CHIPLED_0805
LEDSTR: MA03-1
OLED_L: MA04-1
OLED_R: MA04-1
PAD3, PAD7, PAD9: 3,81/1,4
PAD4, PAD5, PAD6, PAD8: 2,15/1,0
PAD12, PAD13, PAD14, PAD15, PAD16, PAD25: 1,6/0,9
PAD21, PAD22, PAD23, PAD24: 1,6/0,8
Q2, Q3: BSS138; SOT23
Q4: CRYSTALTC26V; TC26V
Q5: IRLML5203; MICRO3
R1, R7: 22k; R0805
R2, R5, R6: 100k; R0805
R3, R4, R8, R9, R10: 10k; R0805
R11: R-EU_R0603; R0603
R12, R13: 10; R2010
R16: 1k; R0805
R18: 470; R0805
R23: 68; R0805
SJ2, SJ3, SJ4, SJ7, SJ11, SJ13, SJ27: SJ2W; SJ_2
SJ5, SJ6, SJ8, SJ9, SJ10, SJ12, SJ26, SJ28: SJ
SPI_L: ML6
SPI_R: ML6
SV2: MA07-2
SV4: BNO055; MA08-1
SV7: MA05-2
T1, T2: BC817-16-NPN-SOT23-BEC; SOT23-BEC
U1: W25Q40BVSN; SO08
XV11: MICROMATCH-6

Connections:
ADC0: C4.1, IC5.17 (PA0), R1.2, R2.1
ADC1: C1.1, IC5.18 (PA1), R6.1, R7.2
BNO055_RESET: IC5.52 (PD2), SV4.8
BUS_FON: BUS_10.3, IC5.34 (PB14)
BUS_RESET: BUS_6.5, BUS_10.5, IC5.51 (PD1)
CAM_PWDN: IC5.13 (PC0); also elsewhere on the board
CHARGE_ON: IC5.36 (PA8), R8.1
ESP_BOOT: SJ12.1; also elsewhere on the board
ESP_RXD: IC5.25 (PC4); also elsewhere on the board
ESP_TXD: IC5.26 (PC5); also elsewhere on the board
FLASH_CS: IC5.41 (PD9), U1.1 (!CS!)
FLASH_HOLD: IC5.55 (PD5), U1.7 (!HOLD!/IO3)
FLASH_WP: IC5.56 (PD6), U1.3 (!WP!/IO2)
GND: (-).1, +-.1, BUS_6.6, BUS_10.8, BUS_10.10, C1.2, C2.2, C3.2, C4.2, C5.-, C6.2, C7.2, C8.2, C9.-, C10.-, C11.1, C26.-, C27.-, IC1.2 (GND), IC2.2 (GND), IC5.9 (VSSA), LED2.C, LEDSTR.3, PAD3.1, PAD4.1, PAD5.1, PAD6.1, PAD7.1, PAD8.1, PAD9.1, PAD23.1, PAD24.1, R1.1, R7.1, R23.2, SJ2.1, SJ4.1, SPI_L.6, SPI_R.6, SV2.3, SV2.5, SV2.7, SV2.9, SV2.11, SV2.13, SV4.2, SV4.5, SV7.1, SV7.2, T1.E, T2.E, U1.4 (GND), XV11.5, XV11.6; also elsewhere on the board
INT: BUS_6.1, BUS_10.9, IC5.5 (PC15), SV4.6; also elsewhere on the board
LCD_1: OLED_L.1, OLED_R.1, SJ2.2
LCD_2: OLED_L.2, OLED_R.2, SJ4.2
LCD_SCL: OLED_L.3, OLED_R.3, SJ7.2
LCD_SDA: OLED_L.4, OLED_R.4, SJ3.2
LED1: IC5.14 (PC1), LED1B.A
LED2: IC5.19 (PA2), R11.2
LEDSTRB: LEDSTR.2, R18.1
LIDAR_M: IC5.50 (PD0), R16.2
LIDAR_RX: IC5.20 (PA3), XV11.1
L_RST_0: IC5.53 (PD3); also elsewhere on the board
L_RST_1: IC5.28 (PB1); also elsewhere on the board
L_RST_2: IC5.54 (PD4); also elsewhere on the board
L_RST_3: IC5.57 (PB3); also elsewhere on the board
L_RST_4: IC5.58 (PB4); also elsewhere on the board
L_RST_5: IC5.59 (PB5); also elsewhere on the board
L_RST_6: IC5.60 (PB6); also elsewhere on the board
L_RST_7: IC5.61 (PB7); also elsewhere on the board
L_RST_8: IC5.39 (PC7); also elsewhere on the board
L_RST_9: IC5.38 (PC6); also elsewhere on the board
L_RST_10: IC5.21 (PA4), IC5.32 (PB12); also elsewhere on the board
L_RST_11: IC5.33 (PB13); also elsewhere on the board
unnamed: IC5.11 (OSC_OUT), Q4.2
unnamed: IC5.10 (OSC_IN), Q4.1, SJ12.2
unnamed: IC5.40 (PD8), R18.2
unnamed: IC5.7 (VREF+), IC5.8 (VDDA), SJ13.2
unnamed: LED2.A, R11.1
unnamed: SJ10.1, SV2.8
unnamed: SJ9.1, SV2.6
unnamed: Q5.1 (G), R5.1, T1.C
unnamed: R8.2, T1.B
unnamed: R16.1, T2.B
unnamed: D5.C, SJ11.2
unnamed: LED1A.A, LED1B.K (C)
unnamed: LED1A.K (C), R23.1
unnamed: D2.A, T2.C, XV11.2
RPI_11: IC5.48 (PC8); also elsewhere on the board
RPI_12: IC5.49 (PC9); also elsewhere on the board
RPI_13: IC5.64 (PC10); also elsewhere on the board
RPI_14: IC5.1 (PC11); also elsewhere on the board
RPI_15: IC5.2 (PC12); also elsewhere on the board
RPI_16: IC5.3 (PC13); also elsewhere on the board
RPI_18: IC5.4 (PC14); also elsewhere on the board
RPI_CS0: IC5.23 (PA6); also elsewhere on the board
RPI_CS1: IC5.24 (PA7); also elsewhere on the board
SCL: BUS_6.3, BUS_10.7, IC5.37 (PA9), Q3.2 (S), R10.2, SJ7.3, SV4.3; also elsewhere on the board
SCL2: IC5.30 (PB10), SJ6.1, SJ7.1
SDA: BUS_6.4, BUS_10.1, IC5.42 (PA10), Q2.2 (S), R9.2, SJ3.3, SV4.4; also elsewhere on the board
SDA2: IC5.31 (PB11), SJ3.1, SJ5.1
SPI2_MISO: IC5.15 (PC2); also elsewhere on the board
SPI2_MOSI: IC5.16 (PC3); also elsewhere on the board
SPI2_NSS: IC5.63 (PB9); also elsewhere on the board
SPI2_SCK: IC5.62 (PB8); also elsewhere on the board
SPI_CLK: IC5.22 (PA5), SPI_L.3, SPI_R.3, U1.6 (CLK); also elsewhere on the board
SPI_CS: IC5.47 (PA15), SPI_L.5, SPI_R.5; also elsewhere on the board
SPI_MISO: IC5.43 (PA11), SPI_L.1, SPI_R.1, U1.2 (DO/IO1); also elsewhere on the board
SPI_MOSI: IC5.44 (PA12), SPI_L.4, SPI_R.4, U1.5 (DI/IO0); also elsewhere on the board
SWCLK: IC5.46 (PA14); also elsewhere on the board
SWDIO: IC5.45 (PA13); also elsewhere on the board
SWNRES: C11.2, IC5.12 (NRST); also elsewhere on the board
U3.3: BUS_6.2, BUS_10.2, C7.1, C9.+, IC1.3 (VO), Q2.1 (G), Q3.1 (G), R9.1, R10.1, SJ2.3, SJ4.3, SJ9.2, SJ10.2, SJ13.3, SPI_L.2, SPI_R.2, SV4.1, U1.8 (VCC), XV11.4; also elsewhere on the board
U5: BUS_10.4, C2.1, C5.+, C26.+, C27.+, IC1.1 (VI), LEDSTR.1, SJ8.2, SJ26.1, SJ27.1; also elsewhere on the board
U5M: D2.C, SJ27.2, XV11.3
UCH: (+).1, D1.A
UCH1: D1.C, PAD21.1, R2.2, SJ11.3, SJ28.2
UCH2: D4.A, PAD22.1, Q5.2 (S), R5.2, SJ28.1
UCH3: C6.1, IC3.3 (IN), Q5.3 (D)
UCH4: IC3.4 (OUT), R12.1, R13.1
UCH5: D3.A, IC3.1 (ADJ), R12.2, R13.2
UCH6: +-.2, BUS_10.6, D5.A, PAD25.1
USTBY: C8.1, C10.+, IC2.3 (VO), IC5.6 (VBAT), SJ13.1; also elsewhere on the board
VB: D3.C, R6.2, SV2.14
VBAT: C3.1, D4.C, IC2.1 (VI), SJ11.1, SJ27.3, SV2.12
VREG: SJ8.1, SV2.10
ZUMO_5V: R3.1, R4.1, SJ26.2, SV7.3, SV7.4
ZUMO_RXD: IC5.29 (PB2), SV7.5
ZUMO_SCL: Q3.3 (D), R4.2, SJ6.2, SV7.8
ZUMO_SDA: Q2.3 (D), R3.2, SJ5.2, SV7.7
ZUMO_SHDN: IC5.35 (PB15), SV2.1; also elsewhere on the board
ZUMO_TXD: IC5.27 (PB0), SV7.6

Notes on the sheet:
(V1.3)

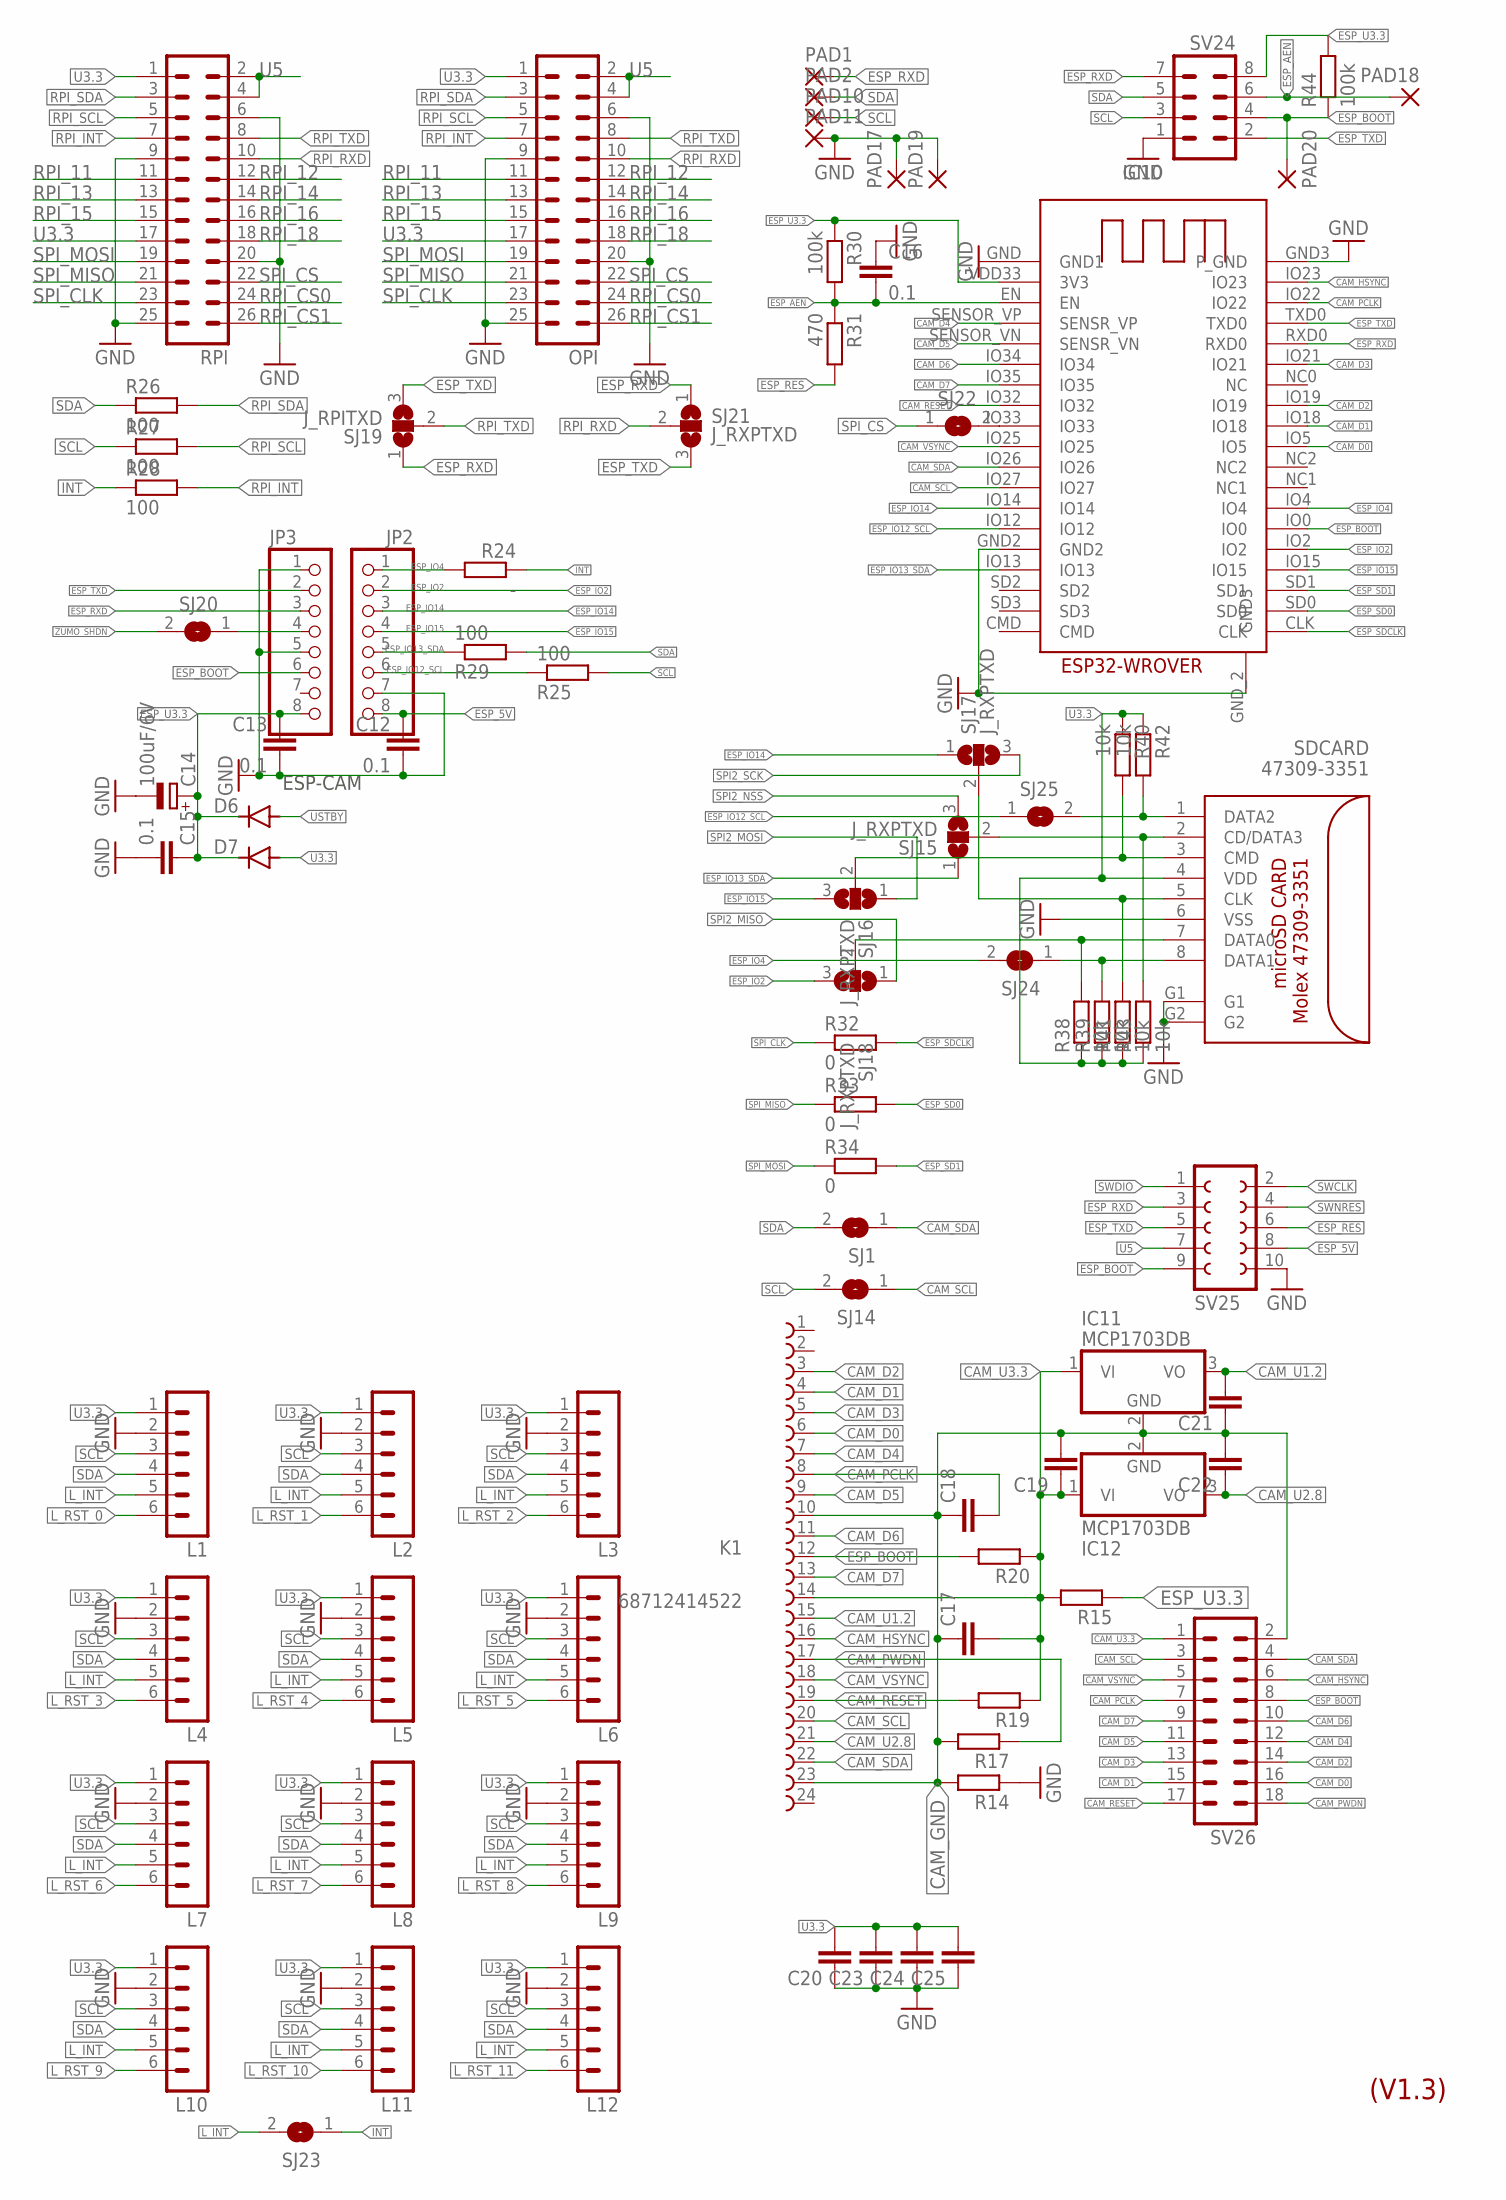
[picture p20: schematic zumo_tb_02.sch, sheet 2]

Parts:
C12, C13, C15, C16: 0.1; C0805
C14: 100uF/6V; B/3528-21R
C17, C18, C19, C20, C21, C22, C23, C24, C25: C-EUC0603; C0603
D6, D7: DIODE-MICROMELF-W; MICROMELF-W
IC10: ESP32-WROVER
IC11, IC12: MCP1703DB; SOT223
JP2, JP3: PINHD-1X8_2.54-SMD; 1X08SMD
K1: 68712414522
L1, L2, L3, L4, L5, L6, L7, L8, L9, L10, L11, L12: MA06-1
OPI: MA13-2
PAD1, PAD2, PAD10, PAD11, PAD17, PAD18, PAD19, PAD20: 1,6/0,9
R14, R15, R17, R19, R20: R-EU_R0603; R0603
R24: -; R0805
R25, R26, R27, R28, R29: 100; R0805
R30, R44: 100k; R0805
R31: 470; R0805
R32, R33, R34: 0; R0805
R38, R39, R40, R41, R42, R43: 10k; R0805
RPI: MA13-2
SDCARD: 47309-3351
SJ1, SJ14, SJ20, SJ22, SJ23, SJ24, SJ25: SJ
SJ15, SJ16, SJ17, SJ18, SJ21: J_RXPTXD; SJ_2
SJ19: J_RPITXD; SJ_2
SV24: MA04-2
SV25: FE05-2
SV26: MA09-2

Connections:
CAM_D0: IC10.IO5, K1.6, SV26.16
CAM_D1: IC10.IO18, K1.4, SV26.15
CAM_D2: IC10.IO19, K1.3, SV26.14
CAM_D3: IC10.IO21, K1.5, SV26.13
CAM_D4: IC10.SENSOR_VP (SENSR_VP), K1.7, SV26.12
CAM_D5: IC10.SENSOR_VN (SENSR_VN), K1.9, SV26.11
CAM_D6: IC10.IO34, K1.11, SV26.10
CAM_D7: IC10.IO35, K1.13, SV26.9
CAM_GND: C17.1, C18.1, C19.2, C21.1, C22.2, IC11.2 (GND), IC12.2 (GND), K1.10, K1.23, R14.2, R17.2, SV26.2
CAM_HSYNC: IC10.IO23, K1.16, SV26.6
CAM_PCLK: C18.2, IC10.IO22, K1.8, SV26.7
CAM_PWDN: K1.17, R17.1, SV26.18; also elsewhere on the board
CAM_RESET: IC10.IO32, K1.19, R19.2, SV26.17
CAM_SCL: IC10.IO27, K1.20, SJ14.1, SV26.3
CAM_SDA: IC10.IO26, K1.22, SJ1.1, SV26.4
CAM_U1.2: C21.2, IC11.3 (VO), K1.15
CAM_U2.8: C22.1, IC12.3 (VO), K1.21
CAM_U3.3: C17.2, C19.1, IC11.1 (VI), IC12.1 (VI), K1.14, R15.2, R19.1, R20.1, SV26.1
CAM_VSYNC: IC10.IO25, K1.18, SV26.5
ESPCAM_13: JP3.4, SJ20.1
ESP_5V: C12.1, JP2.8, SV25.8
ESP_AEN: C16.2, IC10.EN, PAD18.1, R30.2, R31.1, SV24.6
ESP_BOOT: IC10.IO0, JP3.6, K1.12, PAD20.1, R20.2, R44.1, SV24.4, SV25.9, SV26.8; also elsewhere on the board
ESP_IO2: IC10.IO2, JP2.2, SJ18.3
ESP_IO4: IC10.IO4, JP2.1, R24.2, SJ24.2
ESP_IO12_SCL: IC10.IO12, JP2.6, R25.1, SJ25.1
ESP_IO13_SDA: IC10.IO13, JP2.5, R29.1, SJ15.1
ESP_IO14: IC10.IO14, JP2.3, SJ17.1
ESP_IO15: IC10.IO15, JP2.4, SJ16.3
ESP_RES: R31.2, SV25.6
ESP_RXD: IC10.RXD0, JP3.3, PAD1.1, SJ19.1, SJ21.1, SV24.7, SV25.3; also elsewhere on the board
ESP_SD0: IC10.SD0, R33.2
ESP_SD1: IC10.SD1, R34.2
ESP_SDCLK: IC10.CLK, R32.2
ESP_TXD: IC10.TXD0, JP3.2, SJ19.3, SJ21.3, SV24.2, SV25.5; also elsewhere on the board
ESP_U3.3: C13.1, C14.+, C15.1, D6.C, D7.C, IC10.VDD33 (3V3), JP3.8, R15.1, R30.1, R44.2, SV24.8
GND: C12.2, C13.2, C14.-, C15.2, C16.1, C20.1, C23.1, C24.1, C25.1, IC10.GND (GND1), IC10.GND2, IC10.GND3 (P_GND), IC10.GND_2 (GND3), JP2.7, JP3.1, JP3.5, L1.2, L2.2, L3.2, L4.2, L5.2, L6.2, L7.2, L8.2, L9.2, L10.2, L11.2, L12.2, OPI.6, OPI.9, OPI.20, OPI.25, PAD11.1, PAD17.1, PAD19.1, R14.1, RPI.6, RPI.9, RPI.20, RPI.25, SDCARD.6 (VSS), SDCARD.G1, SDCARD.G2, SV24.1, SV25.10; also elsewhere on the board
INT: R24.1, R28.1, SJ23.1; also elsewhere on the board
L_INT: L1.5, L2.5, L3.5, L4.5, L5.5, L6.5, L7.5, L8.5, L9.5, L10.5, L11.5, L12.5, SJ23.2
L_RST_0: L1.6; also elsewhere on the board
L_RST_1: L2.6; also elsewhere on the board
L_RST_2: L3.6; also elsewhere on the board
L_RST_3: L4.6; also elsewhere on the board
L_RST_4: L5.6; also elsewhere on the board
L_RST_5: L6.6; also elsewhere on the board
L_RST_6: L7.6; also elsewhere on the board
L_RST_7: L8.6; also elsewhere on the board
L_RST_8: L9.6; also elsewhere on the board
L_RST_9: L10.6; also elsewhere on the board
L_RST_10: L11.6; also elsewhere on the board
L_RST_11: L12.6; also elsewhere on the board
unnamed: IC10.IO33, SJ22.2
RPI_11: OPI.11, RPI.11; also elsewhere on the board
RPI_12: OPI.12, RPI.12; also elsewhere on the board
RPI_13: OPI.13, RPI.13; also elsewhere on the board
RPI_14: OPI.14, RPI.14; also elsewhere on the board
RPI_15: OPI.15, RPI.15; also elsewhere on the board
RPI_16: OPI.16, RPI.16; also elsewhere on the board
RPI_18: OPI.18, RPI.18; also elsewhere on the board
RPI_CS0: OPI.24, RPI.24; also elsewhere on the board
RPI_CS1: OPI.26, RPI.26; also elsewhere on the board
RPI_INT: OPI.7, R28.2, RPI.7
RPI_RXD: OPI.10, RPI.10, SJ21.2
RPI_SCL: OPI.5, R27.2, RPI.5
RPI_SDA: OPI.3, R26.2, RPI.3
RPI_TXD: OPI.8, RPI.8, SJ19.2
SCL: L1.3, L2.3, L3.3, L4.3, L5.3, L6.3, L7.3, L8.3, L9.3, L10.3, L11.3, L12.3, PAD10.1, R25.2, R27.1, SJ14.2, SV24.3; also elsewhere on the board
SDA: L1.4, L2.4, L3.4, L4.4, L5.4, L6.4, L7.4, L8.4, L9.4, L10.4, L11.4, L12.4, PAD2.1, R26.1, R29.2, SJ1.2, SV24.5; also elsewhere on the board
SD_CLK: R41.2, SDCARD.5 (CLK), SJ17.2
SD_CMD: R40.2, SDCARD.3 (CMD), SJ16.2
SD_DAT0: R38.2, SDCARD.7 (DATA0), SJ18.2
SD_DAT1: R39.2, SDCARD.8 (DATA1), SJ24.1
SD_DAT2: R42.2, SDCARD.1 (DATA2), SJ25.2
SD_DAT3: R43.2, SDCARD.2 (CD/DATA3), SJ15.2
SPI2_MISO: SJ18.1; also elsewhere on the board
SPI2_MOSI: SJ16.1; also elsewhere on the board
SPI2_NSS: SJ15.3; also elsewhere on the board
SPI2_SCK: SJ17.3; also elsewhere on the board
SPI_CLK: OPI.23, R32.1, RPI.23; also elsewhere on the board
SPI_CS: OPI.22, RPI.22, SJ22.1; also elsewhere on the board
SPI_MISO: OPI.21, R33.1, RPI.21; also elsewhere on the board
SPI_MOSI: OPI.19, R34.1, RPI.19; also elsewhere on the board
SWCLK: SV25.2; also elsewhere on the board
SWDIO: SV25.1; also elsewhere on the board
SWNRES: SV25.4; also elsewhere on the board
U3.3: C20.2, C23.2, C24.2, C25.2, D7.A, L1.1, L2.1, L3.1, L4.1, L5.1, L6.1, L7.1, L8.1, L9.1, L10.1, L11.1, L12.1, OPI.1, OPI.17, R38.1, R39.1, R40.1, R41.1, R42.1, R43.1, RPI.1, RPI.17, SDCARD.4 (VDD); also elsewhere on the board
U5: OPI.2, OPI.4, RPI.2, RPI.4, SV25.7; also elsewhere on the board
USTBY: D6.A; also elsewhere on the board
ZUMO_SHDN: SJ20.2; also elsewhere on the board

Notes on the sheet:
ESP-CAM
(V1.3)

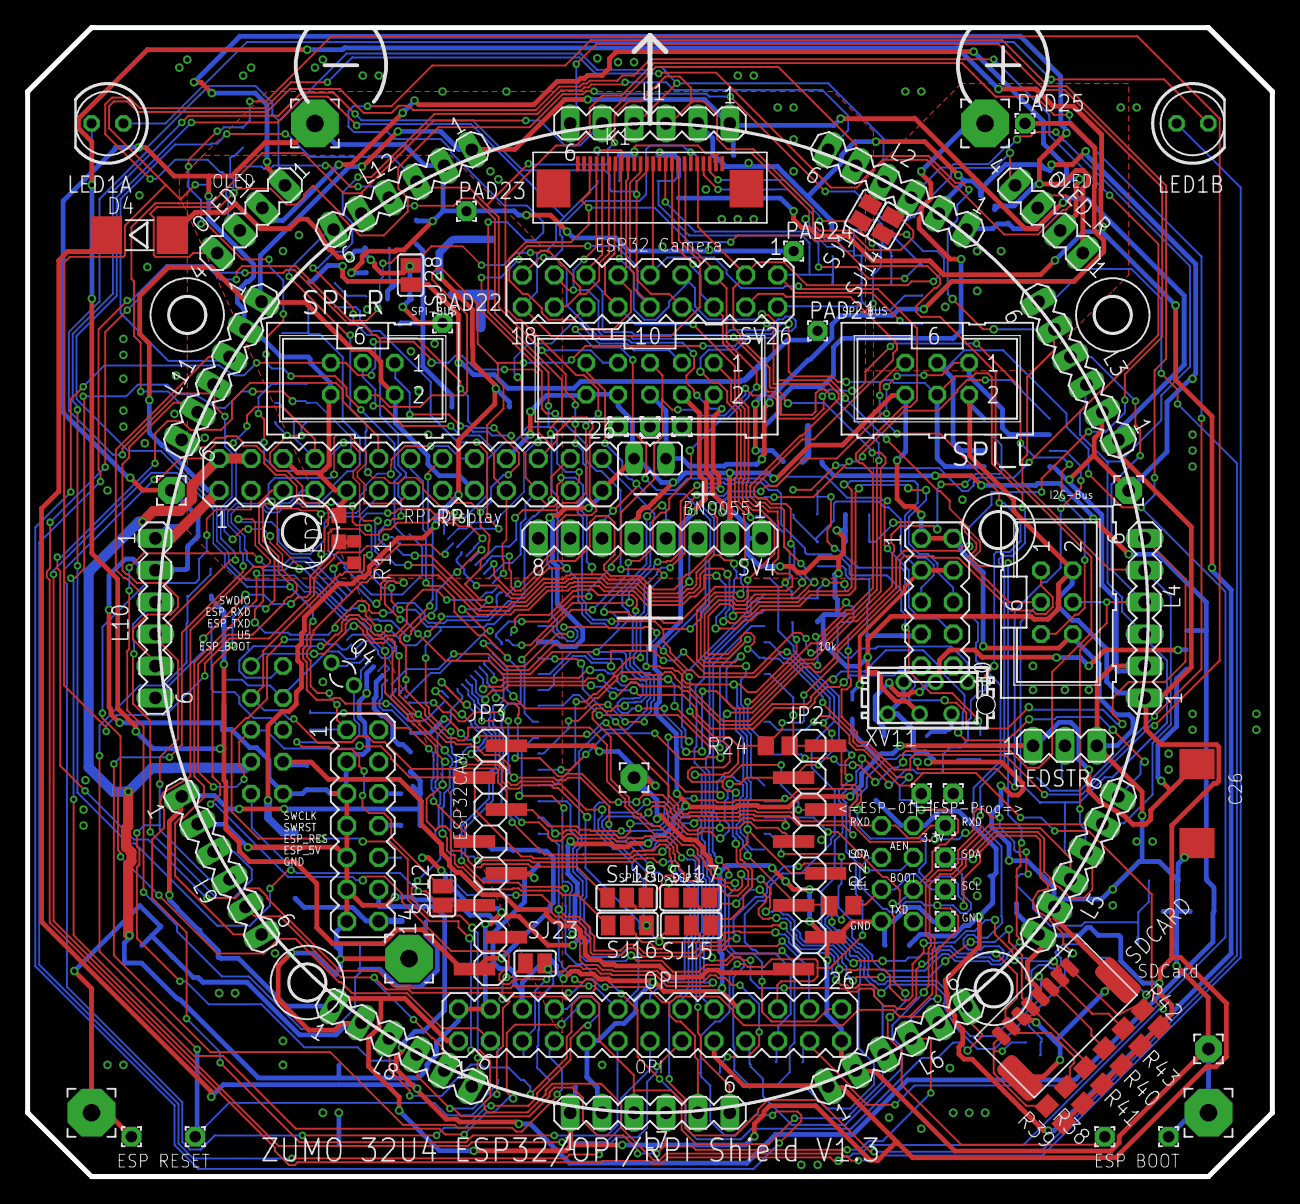
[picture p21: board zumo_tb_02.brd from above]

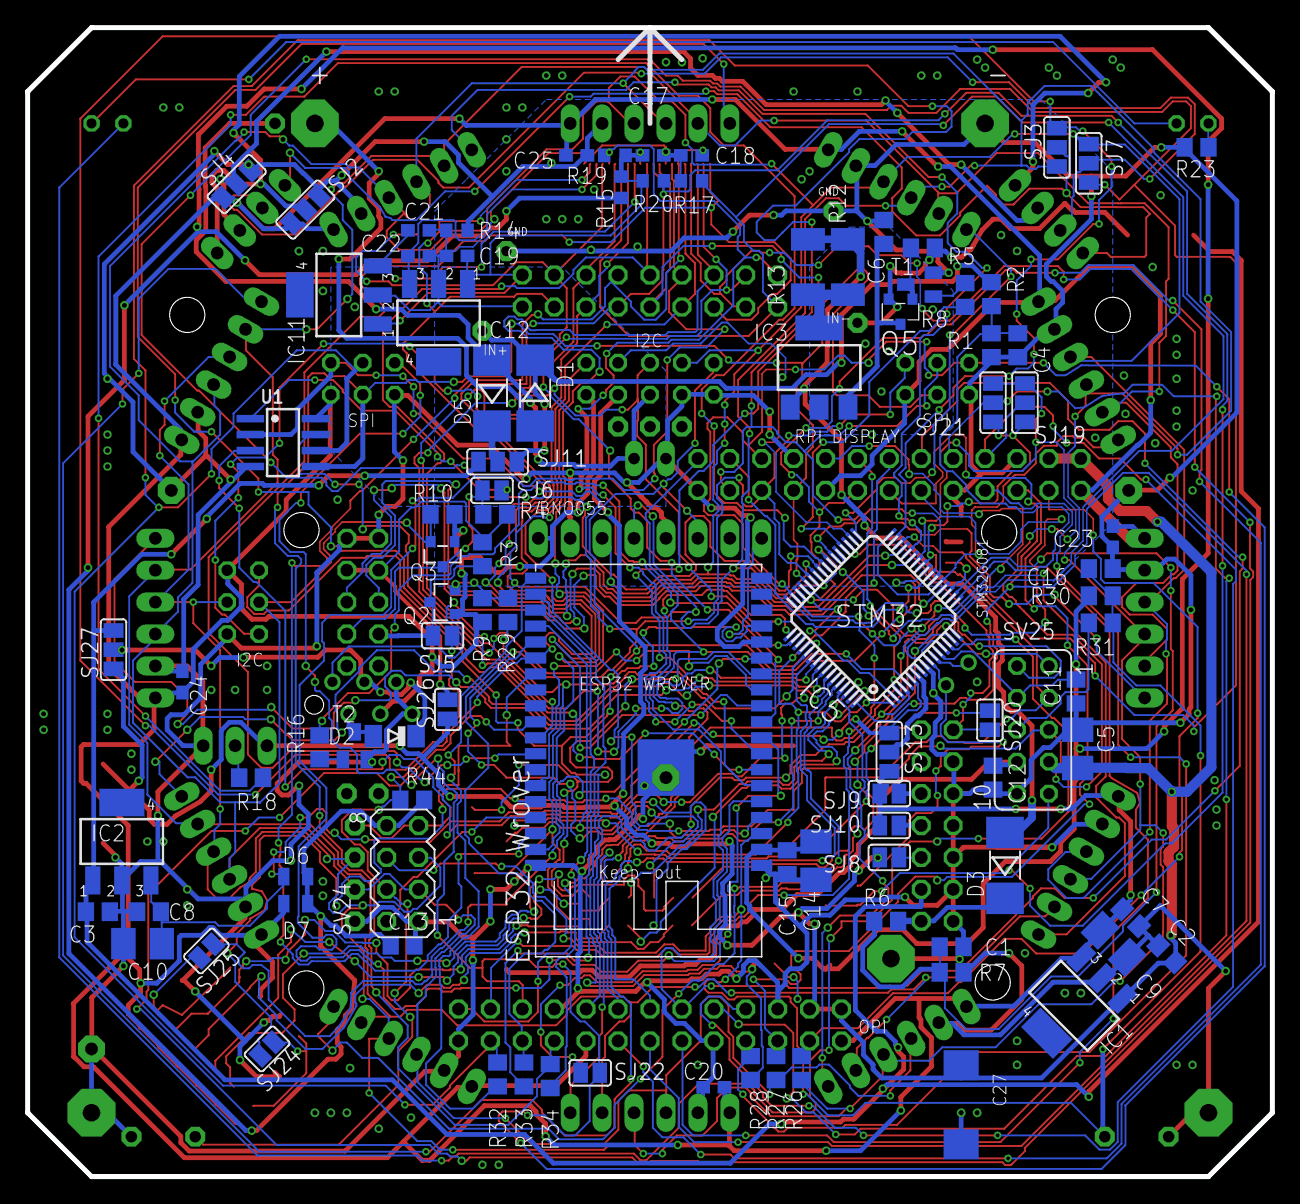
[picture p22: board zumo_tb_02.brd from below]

Board: 2 copper layers, 99.1 x 91.4 mm, 184 parts (96 on the bottom side), 139 nets.

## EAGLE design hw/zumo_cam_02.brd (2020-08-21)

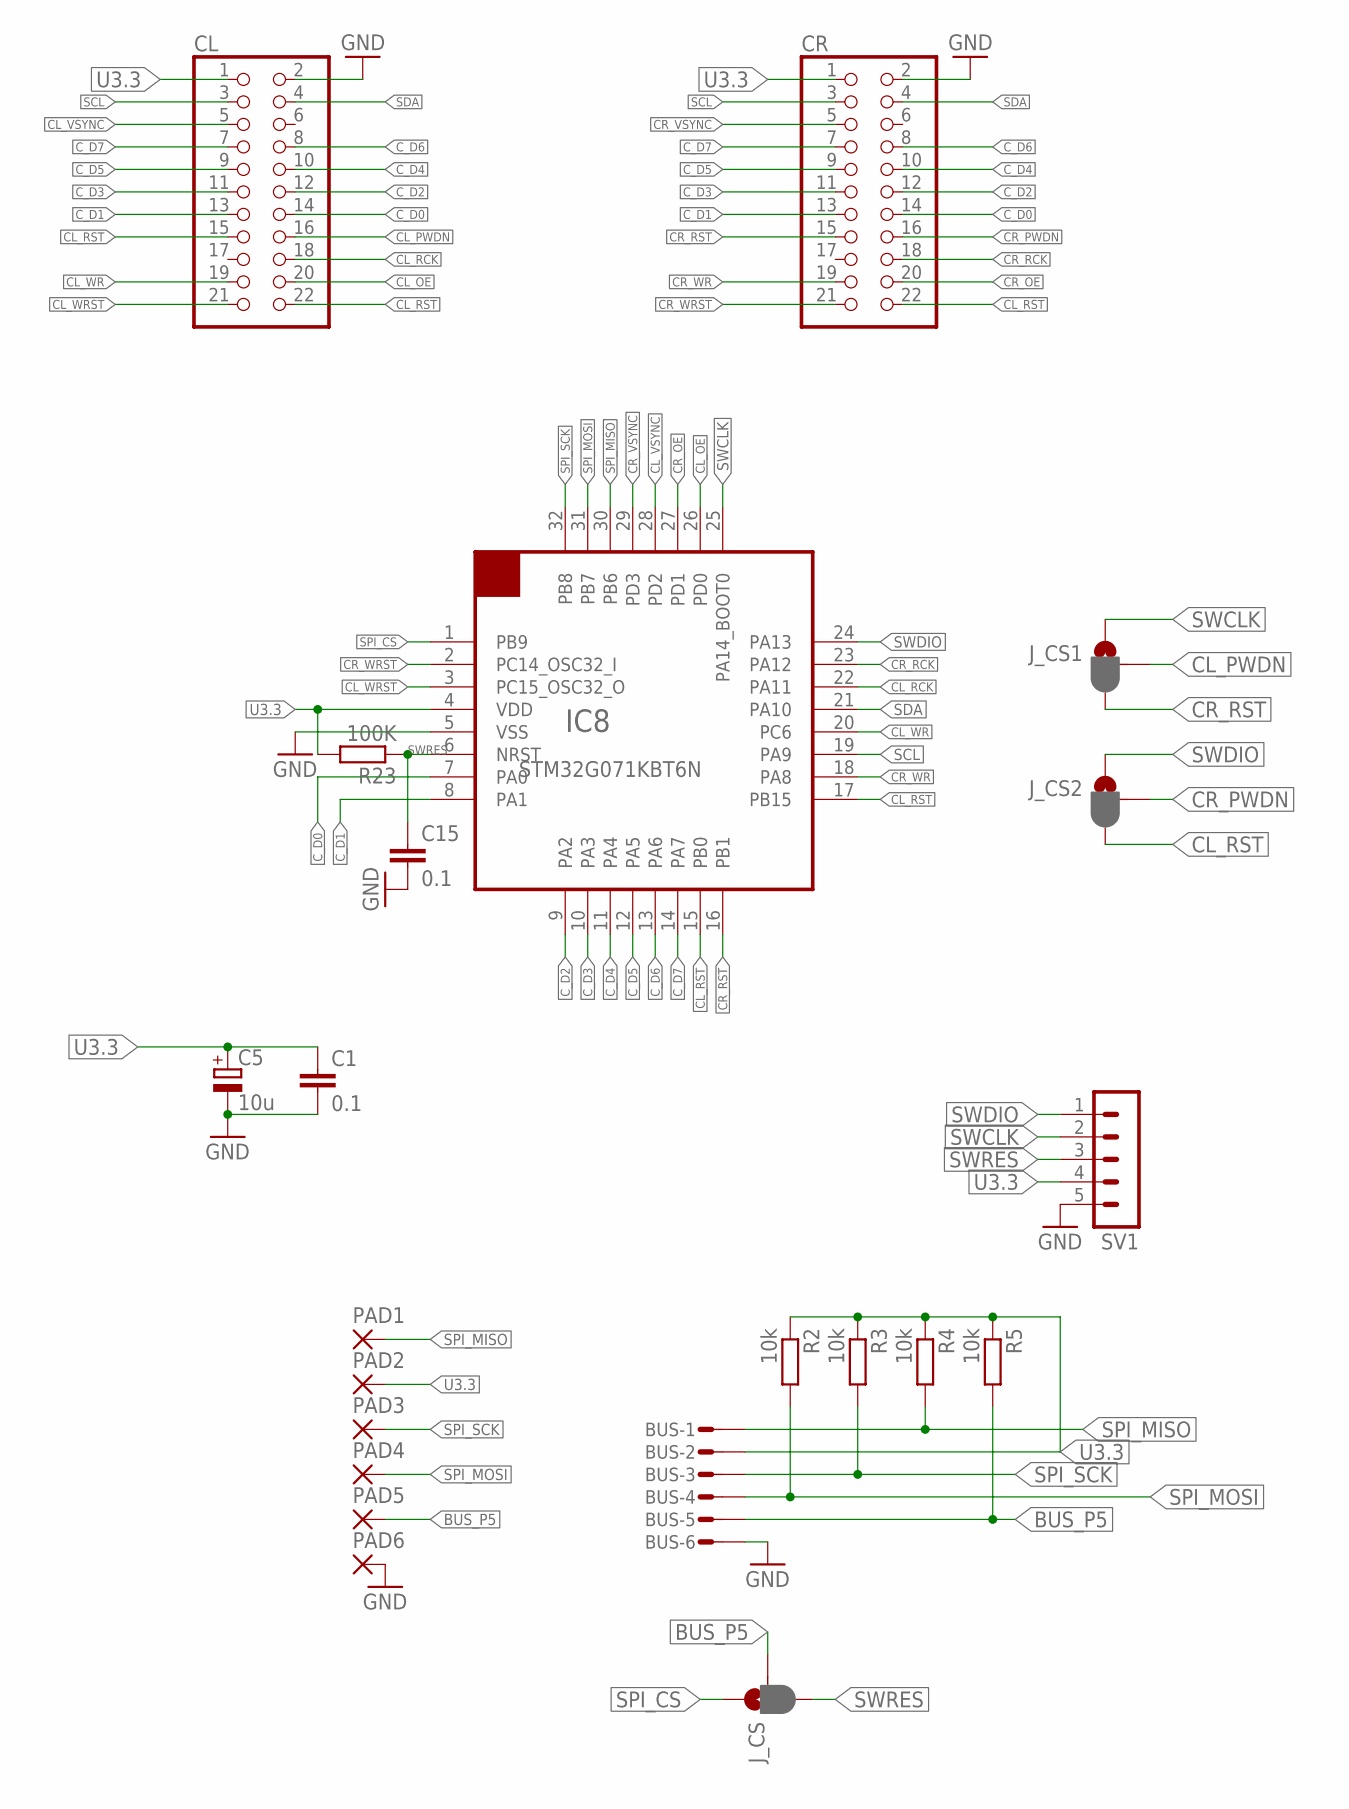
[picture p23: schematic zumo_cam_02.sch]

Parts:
BUS: MICROMATCH-6SMD
C1, C15: 0.1; C0805
C5: 10u; B/3528-21W
CL: PINHD-2X11_2.54-SMD; 2X11SMD
CR: PINHD-2X11_2.54-SMD; 2X11SMD
IC8: STM32G071KBT6N; LQFP-32
J_CS, J_CS1, J_CS2: JUMPER-SMT_3_1-NC_PASTE_NO-SILK; SMT-JUMPER_3_1-NC_PASTE_NO-SILK
PAD1, PAD2, PAD3, PAD4, PAD5, PAD6: SMD2; SMD1,27-2,54
R2, R3, R4, R5: 10k; M0805
R23: 100K; R0805
SV1: MA05-1

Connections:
BUS_P5: BUS.5, J_CS.2, PAD5.1, R5.2
CL_OE: CL.20, IC8.26 (PD0)
CL_PWDN: CL.16, J_CS1.2
CL_RCK: CL.18, IC8.22 (PA11)
CL_RST: CL.15, CL.22, CR.22, IC8.15 (PB0), IC8.17 (PB15), J_CS2.3
CL_VSYNC: CL.5, IC8.28 (PD2)
CL_WR: CL.19, IC8.20 (PC6)
CL_WRST: CL.21, IC8.3 (PC15_OSC32_O)
CR_OE: CR.20, IC8.27 (PD1)
CR_PWDN: CR.16, J_CS2.2
CR_RCK: CR.18, IC8.23 (PA12)
CR_RST: CR.15, IC8.16 (PB1), J_CS1.3
CR_VSYNC: CR.5, IC8.29 (PD3)
CR_WR: CR.19, IC8.18 (PA8)
CR_WRST: CR.21, IC8.2 (PC14_OSC32_I)
C_D0: CL.14, CR.14, IC8.7 (PA0)
C_D1: CL.13, CR.13, IC8.8 (PA1)
C_D2: CL.12, CR.12, IC8.9 (PA2)
C_D3: CL.11, CR.11, IC8.10 (PA3)
C_D4: CL.10, CR.10, IC8.11 (PA4)
C_D5: CL.9, CR.9, IC8.12 (PA5)
C_D6: CL.8, CR.8, IC8.13 (PA6)
C_D7: CL.7, CR.7, IC8.14 (PA7)
GND: BUS.6, C1.2, C5.-, C15.2, CL.2, CR.2, IC8.5 (VSS), PAD6.1, SV1.5
SCL: CL.3, CR.3, IC8.19 (PA9)
SDA: CL.4, CR.4, IC8.21 (PA10)
SPI_CS: IC8.1 (PB9), J_CS.1
SPI_MISO: BUS.1, IC8.30 (PB6), PAD1.1, R4.2
SPI_MOSI: BUS.4, IC8.31 (PB7), PAD4.1, R2.2
SPI_SCK: BUS.3, IC8.32 (PB8), PAD3.1, R3.2
SWCLK: IC8.25 (PA14_BOOT0), J_CS1.1, SV1.2
SWDIO: IC8.24 (PA13), J_CS2.1, SV1.1
SWRES: C15.1, IC8.6 (NRST), J_CS.3, R23.1, SV1.3
U3.3: BUS.2, C1.1, C5.+, CL.1, CR.1, IC8.4 (VDD), PAD2.1, R2.1, R3.1, R4.1, R5.1, R23.2, SV1.4

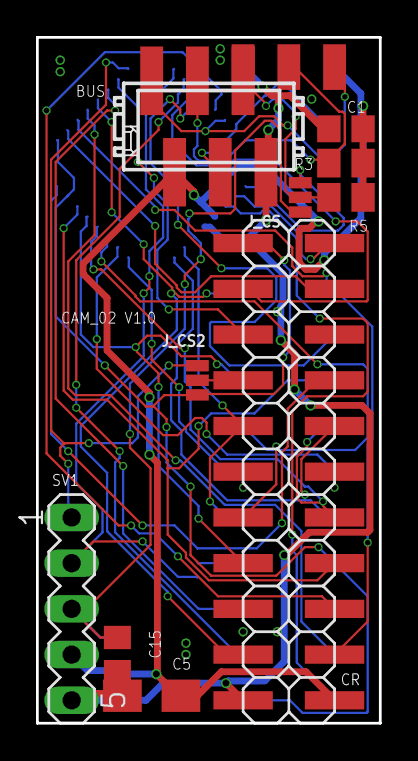
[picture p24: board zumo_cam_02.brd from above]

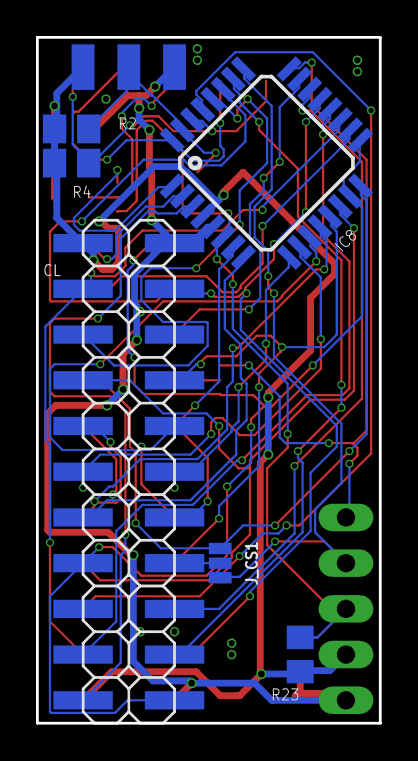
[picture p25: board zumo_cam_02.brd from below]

Board: 2 copper layers, 19.1 x 38.1 mm, 22 parts (9 on the bottom side), 34 nets.

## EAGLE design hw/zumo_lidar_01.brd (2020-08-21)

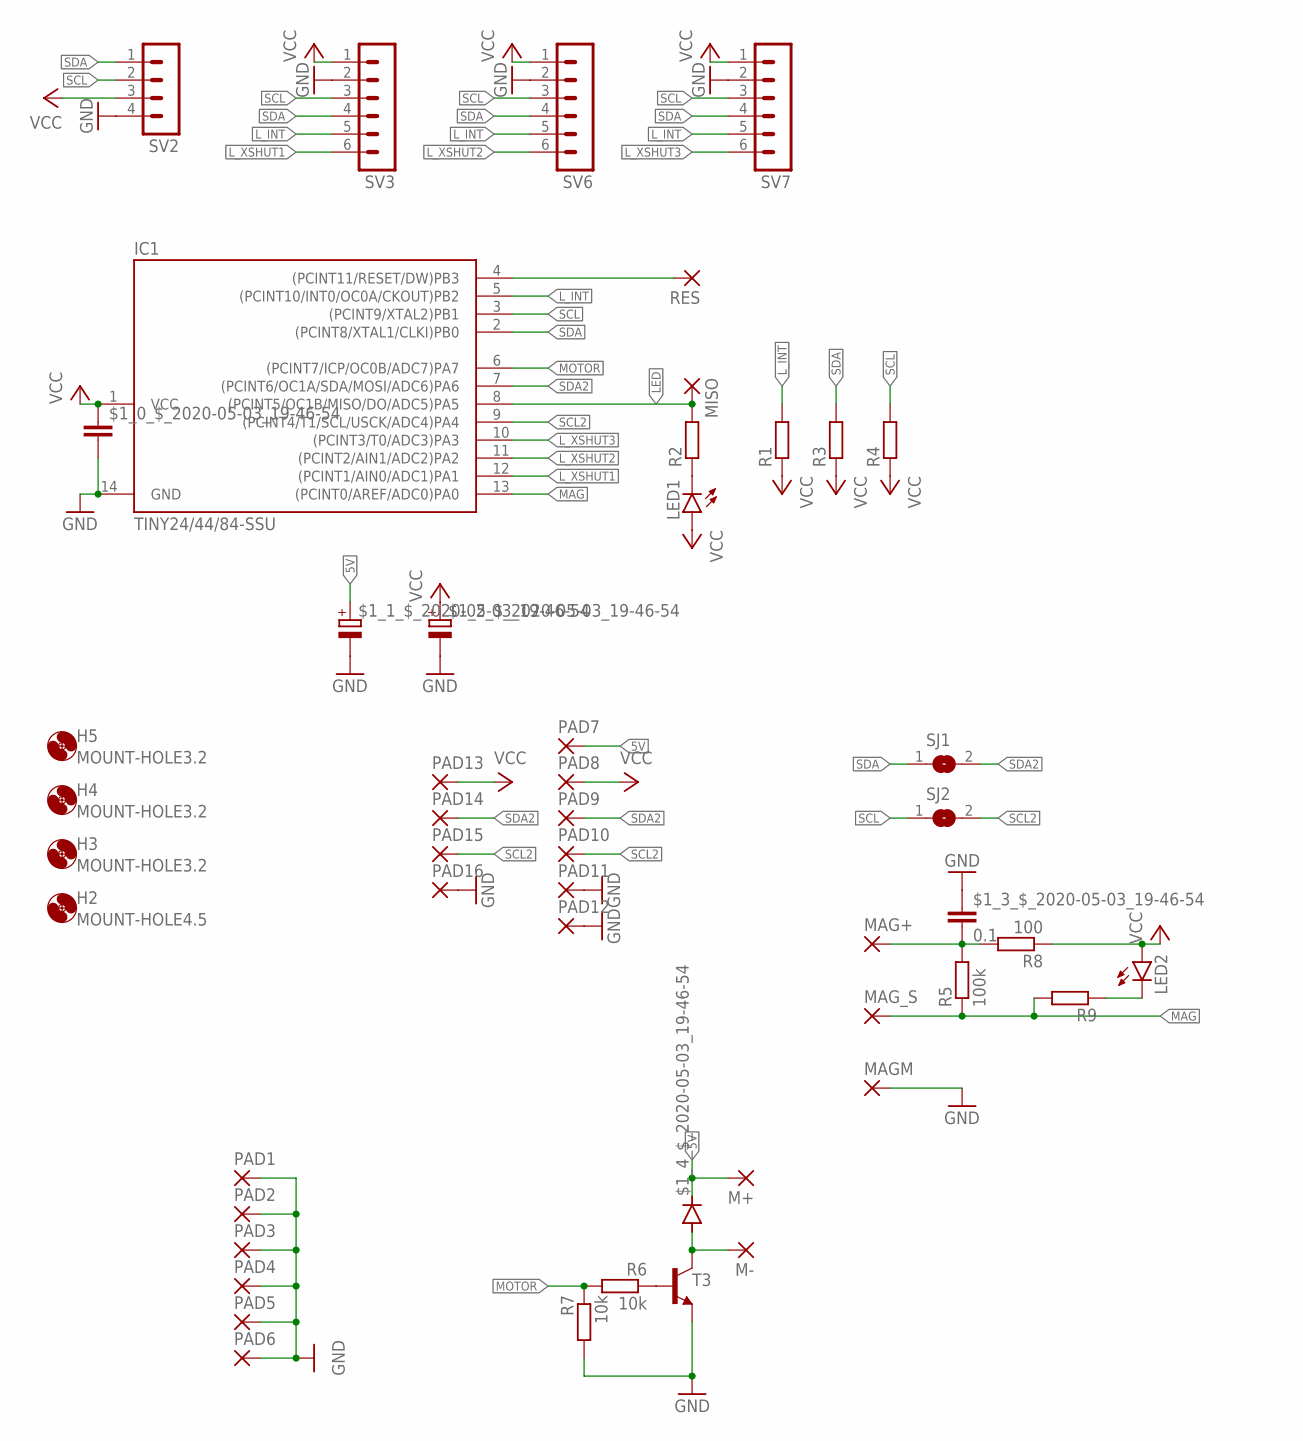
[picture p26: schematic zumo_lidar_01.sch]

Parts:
$1_0_$_2020-05-03_19-46-54: C-EUC0805; C0805
$1_1_$_2020-05-03_19-46-54, $1_2_$_2020-05-03_19-46-54: CPOL-EUSMCC; SMC_C
$1_3_$_2020-05-03_19-46-54: 0.1; C0805
$1_4_$_2020-05-03_19-46-54: DIODE-MINIMELF; MINIMELF
H2: MOUNT-HOLE4.5; 4,5
H3, H4, H5: MOUNT-HOLE3.2; 3,2
IC1: TINY24/44/84-SSU; SOIC14
LED1, LED2: LEDSML0805; SML0805
M+: 1,6/0,8
M-: 1,6/0,8
MAG+: 1,6/0,8
MAGM: 1,6/0,8
MAG_S: 1,6/0,8
MISO: 1,6/0,8
PAD1, PAD2, PAD3, PAD4, PAD5, PAD6: 2,54/1,1
PAD7, PAD8, PAD9, PAD10, PAD11, PAD12, PAD13, PAD14, PAD15, PAD16: 1,6/0,8
R1, R2, R3, R4, R9: R-EU_M0805; M0805
R5: 100k; M0805
R6, R7: 10k; R0805
R8: 100; M0805
RES: 1,6/0,8
SJ1, SJ2: SJ
SV2: MA04-1
SV3, SV6, SV7: MA06-1
T3: BC817-16-NPN-SOT23-BEC; SOT23-BEC

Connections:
5V: $1_1_$_2020-05-03_19-46-54.+, $1_4_$_2020-05-03_19-46-54.C, M+.1, PAD7.1
GND: $1_0_$_2020-05-03_19-46-54.2, $1_1_$_2020-05-03_19-46-54.-, $1_2_$_2020-05-03_19-46-54.-, $1_3_$_2020-05-03_19-46-54.1, IC1.14 (GND), MAGM.1, PAD1.1, PAD2.1, PAD3.1, PAD4.1, PAD5.1, PAD6.1, PAD11.1, PAD12.1, PAD16.1, R7.2, SV2.4, SV3.2, SV6.2, SV7.2, T3.E
LED: IC1.8 ((PCINT5/OC1B/MISO/DO/ADC5)PA5), MISO.1, R2.2
L_INT: IC1.5 ((PCINT10/INT0/OC0A/CKOUT)PB2), R1.2, SV3.5, SV6.5, SV7.5
L_XSHUT1: IC1.12 ((PCINT1/AIN0/ADC1)PA1), SV3.6
L_XSHUT2: IC1.11 ((PCINT2/AIN1/ADC2)PA2), SV6.6
L_XSHUT3: IC1.10 ((PCINT3/T0/ADC3)PA3), SV7.6
MAG: IC1.13 ((PCINT0/AREF/ADC0)PA0), MAG_S.1, R5.1, R9.2
MAGVCC: $1_3_$_2020-05-03_19-46-54.2, MAG+.1, R5.2, R8.2
MOTOR: IC1.6 ((PCINT7/ICP/OC0B/ADC7)PA7), R6.2, R7.1
unnamed: LED1.C, R2.1
unnamed: $1_4_$_2020-05-03_19-46-54.A, M-.1, T3.C
unnamed: R6.1, T3.B
unnamed: LED2.C, R9.1
RESET: IC1.4 ((PCINT11/RESET/DW)PB3), RES.1
SCL: IC1.3 ((PCINT9/XTAL2)PB1), R4.2, SJ2.1, SV2.2, SV3.3, SV6.3, SV7.3
SCL2: IC1.9 ((PCINT4/T1/SCL/USCK/ADC4)PA4), PAD10.1, PAD15.1, SJ2.2
SDA: IC1.2 ((PCINT8/XTAL1/CLKI)PB0), R3.2, SJ1.1, SV2.1, SV3.4, SV6.4, SV7.4
SDA2: IC1.7 ((PCINT6/OC1A/SDA/MOSI/ADC6)PA6), PAD9.1, PAD14.1, SJ1.2
VCC: $1_0_$_2020-05-03_19-46-54.1, $1_2_$_2020-05-03_19-46-54.+, IC1.1 (VCC), LED1.A, LED2.A, PAD8.1, PAD13.1, R1.1, R3.1, R4.1, R8.1, SV2.3, SV3.1, SV6.1, SV7.1

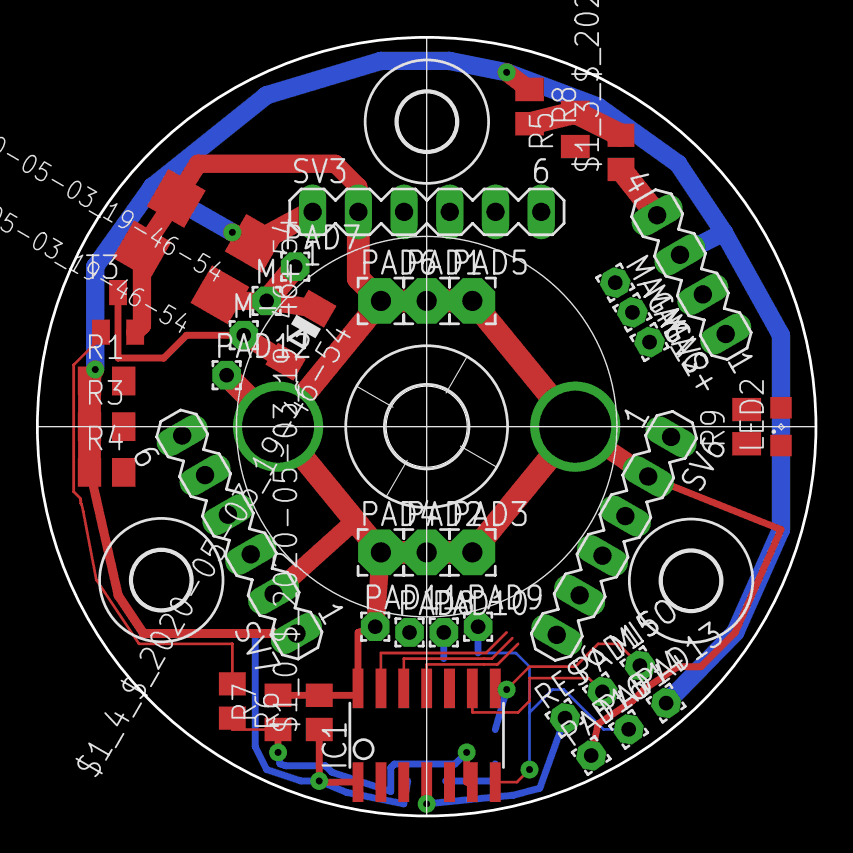
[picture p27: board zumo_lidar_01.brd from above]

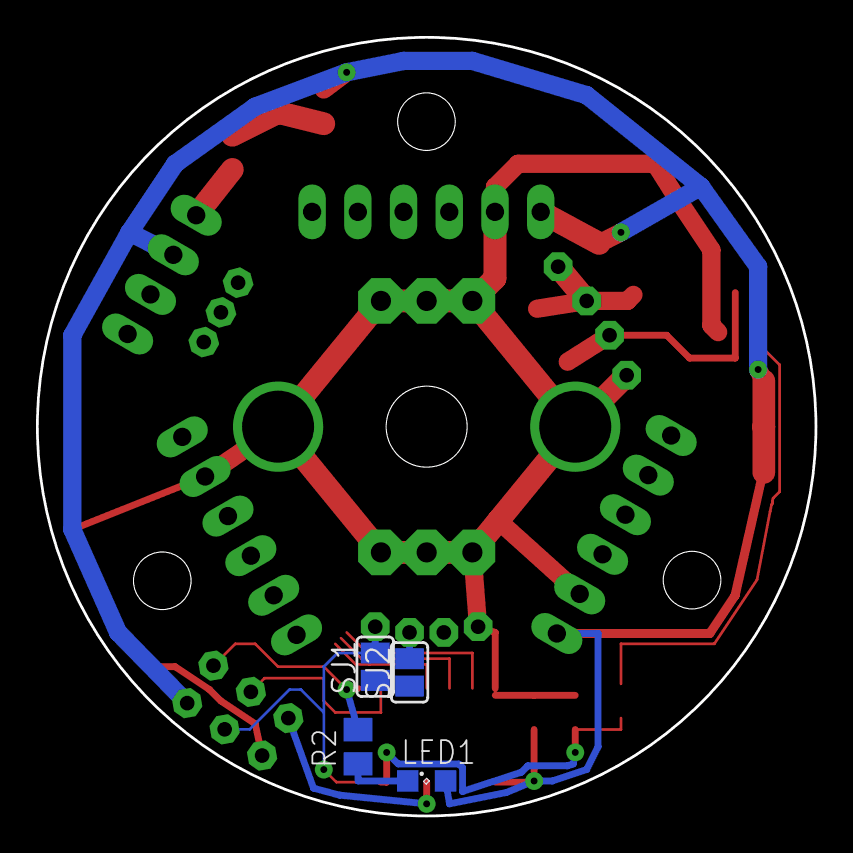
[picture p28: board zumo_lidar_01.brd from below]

Board: 2 copper layers, 43.3 x 43.3 mm, 51 parts (4 on the bottom side), 20 nets.

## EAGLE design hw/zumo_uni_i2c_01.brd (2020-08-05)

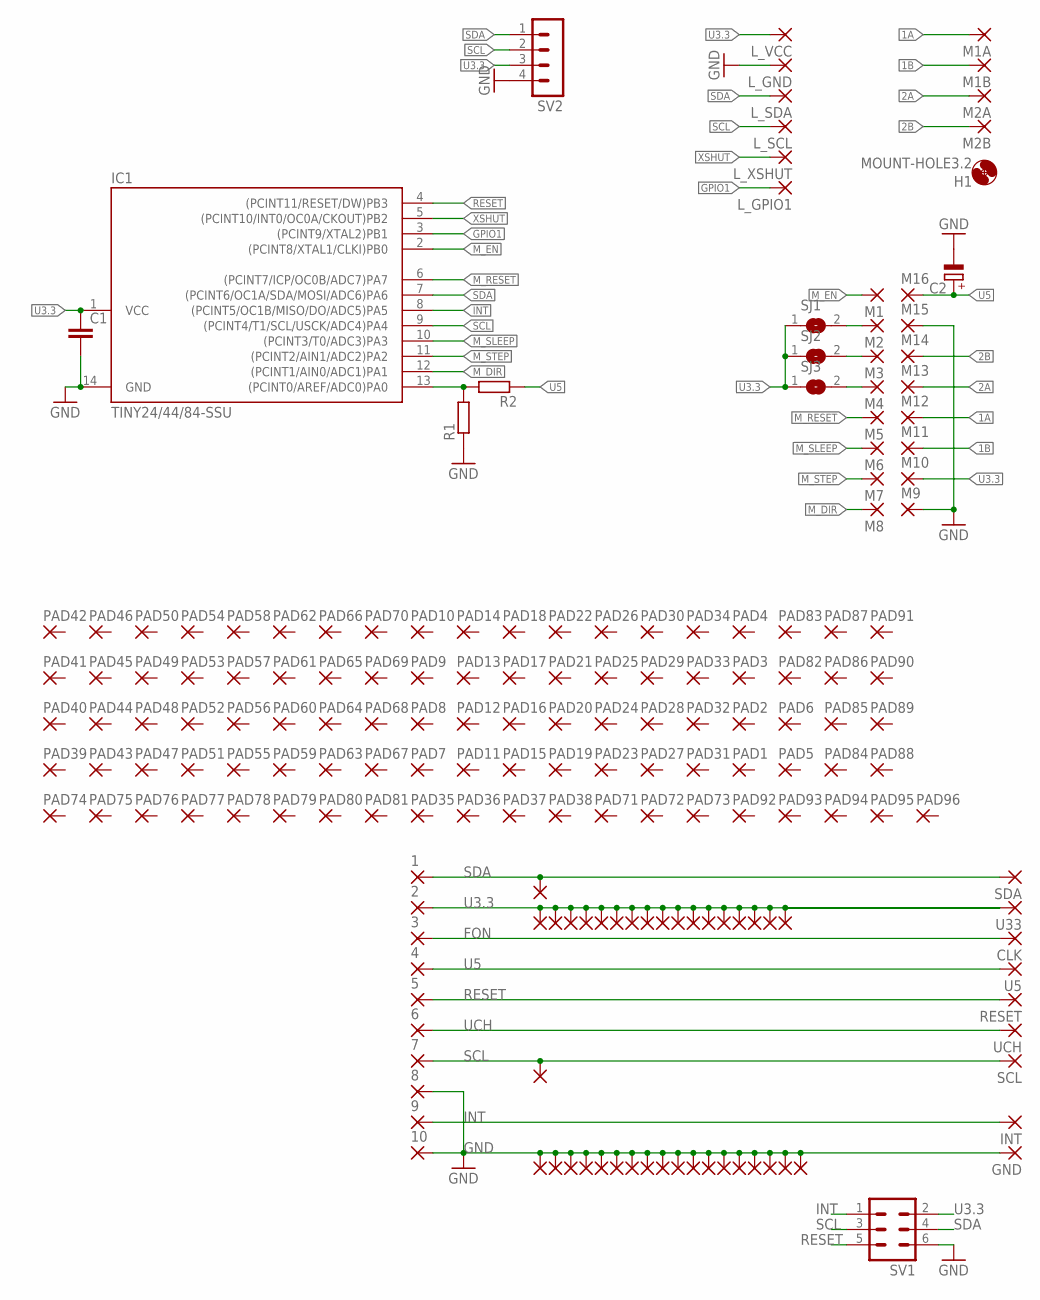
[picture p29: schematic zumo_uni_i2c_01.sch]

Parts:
1, 2, 3, 4, 5, 6, 7, 8, 9, 10: SMD2; SMD1,27-2,54
C1: C-EUC0805; C0805
C2: CPOL-EUSMCC; SMC_C
CLK: 1,6/0,9
GND: 1,6/0,9
H1: MOUNT-HOLE3.2; 3,2
IC1: TINY24/44/84-SSU; SOIC14
INT: 1,6/0,9
L_GND: 1,6/0,8
L_GPIO1: 1,6/0,8
L_SCL: 1,6/0,8
L_SDA: 1,6/0,8
L_VCC: 1,6/0,8
L_XSHUT: 1,6/0,8
M1, M2, M3, M4, M5, M6, M7, M8, M9, M10, M11, M12, M13, M14, M15, M16: 1,6/0,9
M1A, M1B, M2A, M2B: 1,6/0,8
MISO1, MISO4, MISO5, MISO6, MISO7, MISO8, MISO9, MISO10, MISO11, MISO12, MISO13, MISO14, MISO15, MISO16, MISO17, MISO18, MISO19, MISO20, MISO21, MISO22, MISO23, MISO24, MISO25, MISO26, MISO27, MISO28, MISO29, MISO30, MISO31, MISO32, MISO33, MISO34, MISO35, MISO36, MISO37, MISO41, MISO43: 1,6/0,9
PAD1, PAD2, PAD3, PAD4, PAD5, PAD6, PAD7, PAD8, PAD9, PAD10, PAD11, PAD12, PAD13, PAD14, PAD15, PAD16, PAD17, PAD18, PAD19, PAD20, PAD21, PAD22, PAD23, PAD24, PAD25, PAD26, PAD27, PAD28, PAD29, PAD30, PAD31, PAD32, PAD33, PAD34, PAD35, PAD36, PAD37, PAD38, PAD39, PAD40, PAD41, PAD42, PAD43, PAD44, PAD45, PAD46, PAD47, PAD48, PAD49, PAD50, PAD51, PAD52, PAD53, PAD54, PAD55, PAD56, PAD57, PAD58, PAD59, PAD60, PAD61, PAD62, PAD63, PAD64, PAD65, PAD66, PAD67, PAD68, PAD69, PAD70, PAD71, PAD72, PAD73, PAD74, PAD75, PAD76, PAD77, PAD78, PAD79, PAD80, PAD81, PAD82, PAD83, PAD84, PAD85, PAD86, PAD87, PAD88, PAD89, PAD90, PAD91, PAD92, PAD93, PAD94, PAD95, PAD96: 1,6/0,9
R1, R2: R-EU_M0805; M0805
RESET: 1,6/0,9
SCL: 1,6/0,9
SDA: 1,6/0,9
SJ1, SJ2, SJ3: SJ
SV1: ML6
SV2: MA04-1
U5, U33: 1,6/0,9
UCH: 1,6/0,9

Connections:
1A: M1A.1, M12.1
1B: M1B.1, M11.1
2A: M2A.1, M13.1
2B: M2B.1, M14.1
FON: 3.1, CLK.1
GND: 8.1, 10.1, C1.2, C2.-, GND.1, IC1.14 (GND), L_GND.1, M9.1, M15.1, MISO1.1, MISO5.1, MISO6.1, MISO7.1, MISO8.1, MISO9.1, MISO10.1, MISO11.1, MISO12.1, MISO13.1, MISO14.1, MISO15.1, MISO16.1, MISO17.1, MISO18.1, MISO19.1, MISO20.1, MISO43.1, R1.1, SV1.6, SV2.4
GPIO1: IC1.3 ((PCINT9/XTAL2)PB1), L_GPIO1.1
INT: 9.1, IC1.8 ((PCINT5/OC1B/MISO/DO/ADC5)PA5), INT.1, SV1.1
M_DIR: IC1.12 ((PCINT1/AIN0/ADC1)PA1), M8.1
M_EN: IC1.2 ((PCINT8/XTAL1/CLKI)PB0), M1.1
M_MS1: M2.1, SJ1.2
M_MS2: M3.1, SJ2.2
M_MS3: M4.1, SJ3.2
M_RESET: IC1.6 ((PCINT7/ICP/OC0B/ADC7)PA7), M5.1
M_SLEEP: IC1.10 ((PCINT3/T0/ADC3)PA3), M6.1
M_STEP: IC1.11 ((PCINT2/AIN1/ADC2)PA2), M7.1
unnamed: IC1.13 ((PCINT0/AREF/ADC0)PA0), R1.2, R2.2
RESET: 5.1, IC1.4 ((PCINT11/RESET/DW)PB3), RESET.1, SV1.5
SCL: 7.1, IC1.9 ((PCINT4/T1/SCL/USCK/ADC4)PA4), L_SCL.1, MISO41.1, SCL.1, SV1.3, SV2.2
SDA: 1.1, IC1.7 ((PCINT6/OC1A/SDA/MOSI/ADC6)PA6), L_SDA.1, MISO21.1, SDA.1, SV1.4, SV2.1
U3.3: 2.1, C1.1, IC1.1 (VCC), L_VCC.1, M10.1, MISO4.1, MISO22.1, MISO23.1, MISO24.1, MISO25.1, MISO26.1, MISO27.1, MISO28.1, MISO29.1, MISO30.1, MISO31.1, MISO32.1, MISO33.1, MISO34.1, MISO35.1, MISO36.1, MISO37.1, SJ1.1, SJ2.1, SJ3.1, SV1.2, SV2.3, U33.1
U5: 4.1, C2.+, M16.1, R2.1, U5.1
UCH: 6.1, UCH.1
XSHUT: IC1.5 ((PCINT10/INT0/OC0A/CKOUT)PB2), L_XSHUT.1

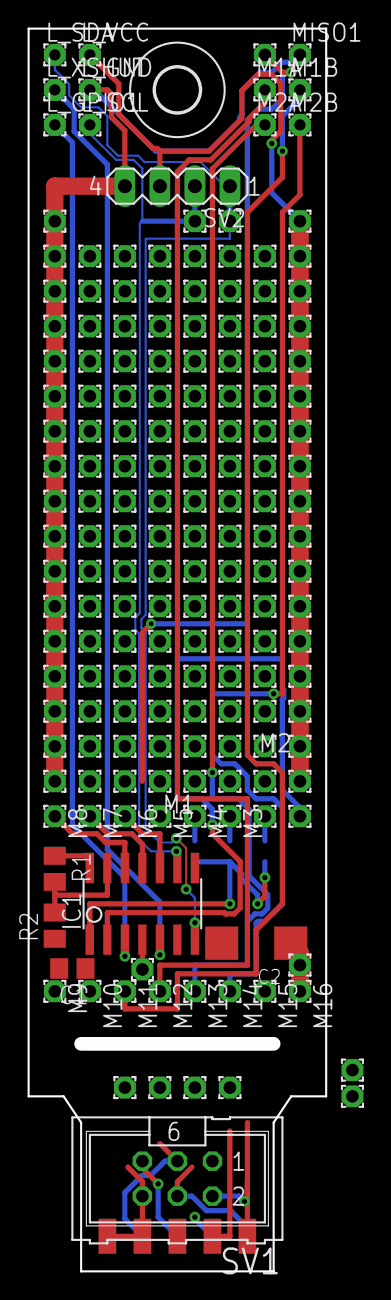
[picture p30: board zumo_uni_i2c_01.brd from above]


Board: 2 copper layers, 21.6 x 90.2 mm, 189 parts (8 on the bottom side), 24 nets.

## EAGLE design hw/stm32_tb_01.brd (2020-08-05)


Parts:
ANT1: 1,6/0,9
C1, C2, C3, C4, C5, C6, C7: C-EUC0805; C0805
IC1: STM32F10XCXT6; TQFP48
PAD1, PAD2, PAD3, PAD4, PAD5, PAD6, PAD7, PAD8, PAD9, PAD10, PAD11, PAD12, PAD13, PAD15, PAD16, PAD17, PAD18, PAD19, PAD20, PAD21, PAD22, PAD23, PAD24, PAD25, PAD26, PAD27, PAD28, PAD29, PAD30, PAD31, PAD32, PAD35: 1,6/0,9
Q1: CSM-7X-DU
Q2: CRYSTALTC26V; TC26V
R1, R2, R3, R4, R5, R6: R-EU_R0805; R0805
SV1: ML6
SV2: MA04-1
U$1: WIRELESS-LORA-RFM95W#THT

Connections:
GND: C1.2, C2.2, C3.1, C4.2, C5.1, C6.1, C7.1, IC1.8 (VSSA), IC1.23 (VSS_1), IC1.35 (VSS_2), IC1.47 (VSS_3), SV1.6, SV2.4, U$1.A1 (GND.1), U$1.A8 (GND.2), U$1.B7 (GND.3)
INT: SV1.1
unnamed: IC1.10 (PA0), PAD1.1
unnamed: IC1.11 (PA1), PAD2.1
unnamed: IC1.12 (PA2), PAD3.1
unnamed: IC1.13 (PA3), PAD4.1
unnamed: IC1.14 (PA4), PAD5.1
unnamed: IC1.15 (PA5), PAD6.1
unnamed: IC1.16 (PA6), PAD7.1
unnamed: IC1.17 (PA7), PAD8.1
unnamed: IC1.43 (PB7), PAD9.1
unnamed: IC1.42 (PB6), PAD10.1
unnamed: IC1.41 (PB5), PAD11.1
unnamed: IC1.40 (PB4), PAD12.1
unnamed: IC1.39 (PB3), PAD13.1
unnamed: IC1.20 (PB2), R5.1
unnamed: IC1.19 (PB1), PAD15.1
unnamed: IC1.18 (PB0), PAD16.1
unnamed: IC1.45 (PB8), PAD17.1
unnamed: IC1.46 (PB9), PAD18.1
unnamed: IC1.21 (PB10), PAD19.1
unnamed: IC1.22 (PB11), PAD20.1
unnamed: IC1.25 (PB12), PAD21.1
unnamed: IC1.26 (PB13), PAD22.1
unnamed: IC1.27 (PB14), PAD23.1
unnamed: IC1.28 (PB15), PAD24.1
unnamed: IC1.29 (PA8), PAD25.1
unnamed: IC1.30 (PA9), PAD26.1
unnamed: IC1.31 (PA10), PAD27.1
unnamed: IC1.33 (PA12), R2.2, R4.2
unnamed: IC1.32 (PA11), R3.2
unnamed: IC1.34 (PA13), PAD30.1
unnamed: IC1.37 (PA14), PAD31.1
unnamed: IC1.38 (PA15), PAD32.1
unnamed: PAD28.1, R3.1
unnamed: PAD29.1, R2.1
unnamed: IC1.2 (PC13), PAD35.1
unnamed: C5.2, IC1.3 (PC14), Q2.1
unnamed: C6.2, IC1.4 (PC15), Q2.2
unnamed: IC1.44 (BOOT0), R6.1
unnamed: C1.1, IC1.5 (PD0/OSC<=), Q1.1
unnamed: C2.1, IC1.6 (PD1/OSC=>), Q1.2
unnamed: C3.2, IC1.9 (VDDA)
unnamed: C4.1, IC1.1 (VBAT)
unnamed: C7.2, IC1.7 (NRST), R1.1
unnamed: ANT1.1, U$1.B8 (ANT)
RESET: SV1.5
SCL: SV1.3, SV2.2
SDA: SV1.4, SV2.1
U3.3: SV1.2
VCC: IC1.24 (VDD_1), IC1.36 (VDD_2), IC1.48 (VDD_3), R1.2, R4.1, SV2.3, U$1.B4 (3.3V)

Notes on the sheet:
STM32 F103C8T6


Board: 2 copper layers, 22.9 x 29.8 mm, 52 parts (1 on the bottom side), 48 nets.

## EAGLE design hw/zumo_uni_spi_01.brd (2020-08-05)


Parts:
CLK: 1,6/0,9
CS: 1,6/0,9
GND: 1,6/0,9
MISO, MISO1, MISO2, MISO3, MISO4, MISO5, MISO6, MISO7, MISO8, MISO9, MISO10, MISO11, MISO12, MISO13, MISO14, MISO15, MISO16, MISO17, MISO18, MISO19, MISO20, MISO21, MISO22, MISO23, MISO24, MISO25, MISO26, MISO27, MISO28, MISO29, MISO30, MISO31, MISO32, MISO33, MISO34, MISO35, MISO36, MISO37, MISO38: 1,6/0,9
MOSI: 1,6/0,9
PAD1, PAD2, PAD3, PAD4, PAD5, PAD6: SMD2; SMD1,27-2,54
PAD7, PAD8, PAD9, PAD10, PAD11, PAD12, PAD13, PAD14, PAD15, PAD16, PAD17, PAD18, PAD19, PAD20, PAD21, PAD22, PAD23, PAD24, PAD25, PAD26, PAD27, PAD28, PAD29, PAD30, PAD31, PAD32, PAD33, PAD34, PAD35, PAD36, PAD37, PAD38, PAD39, PAD40, PAD41, PAD42, PAD43, PAD44, PAD45, PAD46, PAD47, PAD48, PAD49, PAD50, PAD51, PAD52, PAD53, PAD54, PAD55, PAD56, PAD57, PAD58, PAD59, PAD60, PAD61, PAD62, PAD63, PAD64, PAD65, PAD66, PAD67, PAD68, PAD69, PAD70, PAD71, PAD72, PAD73, PAD74, PAD75, PAD76, PAD77, PAD78, PAD79, PAD80, PAD81: 1,6/0,9
U33: 1,6/0,9

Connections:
GND: GND.1, MISO5.1, MISO6.1, MISO7.1, MISO8.1, MISO9.1, MISO10.1, MISO11.1, MISO12.1, MISO13.1, MISO14.1, MISO15.1, MISO16.1, MISO17.1, MISO18.1, MISO19.1, MISO20.1, PAD6.1
SPI_CLK: CLK.1, MISO3.1, PAD3.1
SPI_CS: CS.1, MISO1.1, PAD5.1
SPI_MISO: MISO.1, MISO21.1, PAD1.1
SPI_MOSI: MISO2.1, MOSI.1, PAD4.1
U3.3: MISO4.1, MISO22.1, MISO23.1, MISO24.1, MISO25.1, MISO26.1, MISO27.1, MISO28.1, MISO29.1, MISO30.1, MISO31.1, MISO32.1, MISO33.1, MISO34.1, MISO35.1, MISO36.1, MISO37.1, MISO38.1, PAD2.1, U33.1



Board: 2 copper layers, 19.0 x 48.9 mm, 125 parts (3 on the bottom side), 6 nets.

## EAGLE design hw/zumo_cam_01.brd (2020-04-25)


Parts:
C15: 0.1; C0805
IC8: STM32G071KBT6N; LQFP-32
JP1, JP2: PINHD-2X11_2.54-SMD; 2X11SMD
PAD1, PAD2, PAD3, PAD4, PAD5, PAD6: SMD2; SMD1,27-2,54
R23: 100K; R0805

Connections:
+3V3: JP1.1, JP2.1
CL_OE: IC8.26 (PD0), JP1.20
CL_PWDN: JP1.16
CL_RCK: IC8.22 (PA11), JP1.18
CL_RST: IC8.15 (PB0), IC8.17 (PB15), JP1.15, JP1.22, JP2.22
CL_VSYNC: IC8.28 (PD2), JP1.5
CL_WR: IC8.20 (PC6), JP1.19
CL_WRST: IC8.3 (PC15_OSC32_O), JP1.21
CR_OE: IC8.27 (PD1), JP2.20
CR_PWDN: JP2.16
CR_RCK: IC8.23 (PA12), JP2.18
CR_RST: IC8.16 (PB1), JP2.15
CR_VSYNC: IC8.29 (PD3), JP2.5
CR_WR: IC8.18 (PA8), JP2.19
CR_WRST: IC8.2 (PC14_OSC32_I), JP2.21
C_D0: IC8.7 (PA0), JP1.14, JP2.14
C_D1: IC8.8 (PA1), JP1.13, JP2.13
C_D2: IC8.9 (PA2), JP1.12, JP2.12
C_D3: IC8.10 (PA3), JP1.11, JP2.11
C_D4: IC8.11 (PA4), JP1.10, JP2.10
C_D5: IC8.12 (PA5), JP1.9, JP2.9
C_D6: IC8.13 (PA6), JP1.8, JP2.8
C_D7: IC8.14 (PA7), JP1.7, JP2.7
GND: C15.2, IC8.5 (VSS), JP1.2, JP2.2, PAD6.1
SCL: IC8.19 (PA9), JP1.3, JP2.3
SDA: IC8.21 (PA10), JP1.4, JP2.4
SPI_CLK: PAD3.1
SPI_CS: IC8.1 (PB9), PAD5.1
SPI_MISO: IC8.30 (PB6), PAD1.1
SPI_MOSI: IC8.31 (PB7), PAD4.1
SPI_SCK: IC8.32 (PB8)
SWCLK: IC8.25 (PA14_BOOT0)
SWDIO: IC8.24 (PA13)
SWNRES: C15.1, IC8.6 (NRST), R23.1
U3.3: IC8.4 (VDD), PAD2.1, R23.2



Board: 2 copper layers, 29.2 x 26.0 mm, 11 parts (5 on the bottom side), 29 nets.

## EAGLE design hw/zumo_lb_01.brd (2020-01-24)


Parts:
D1, D2, D3, D4, D5, D6, D7, D8: DIODE-MINIMELF; MINIMELF
IC1: TINY24/44/84-SSU; SOIC14
IC2: L293D; DIL16
JP1: JP1E; JP1
PAD1, PAD2, PAD3, PAD4, PAD5, PAD6, PAD7, PAD8, PAD9, PAD10: SMD2; SMD1,27-2,54
PAD11: 3,81/1,4
SJ1, SJ2, SJ4: SJ2W; SJ_2
SV2: MA04-1
SV3: FE05-2

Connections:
FON: IC1.3 ((PCINT9/XTAL2)PB1), PAD3.1
GND: D1.A, D2.A, D5.A, D6.A, IC1.14 (GND), IC2.4 (GND1), IC2.5 (GND2), IC2.12 (GND4), IC2.13 (GND3), JP1.1, PAD8.1, PAD10.1, PAD11.1, SJ1.1, SJ4.1, SV3.2
INT: IC1.8 ((PCINT5/OC1B/MISO/DO/ADC5)PA5), PAD9.1
LCD_1: SJ1.2, SV2.1
LCD_2: SJ4.2, SV2.2
L_INT: IC1.5 ((PCINT10/INT0/OC0A/CKOUT)PB2), SV3.5
L_RES: IC1.2 ((PCINT8/XTAL1/CLKI)PB0), SV3.6
M1A: IC1.10 ((PCINT3/T0/ADC3)PA3), IC2.2 (1A)
M1Y: D1.C, D3.A, IC2.3 (1Y), SV3.7
M2A: IC1.11 ((PCINT2/AIN1/ADC2)PA2), IC2.7 (2A)
M2Y: D2.C, D4.A, IC2.6 (2Y), SV3.8
M3A: IC1.12 ((PCINT1/AIN0/ADC1)PA1), IC2.10 (3A)
M3Y: D6.C, D8.A, IC2.11 (3Y), SV3.9
M4A: IC1.13 ((PCINT0/AREF/ADC0)PA0), IC2.15 (4A)
M4Y: D5.C, D7.A, IC2.14 (4Y), SV3.10
unnamed: SJ1.3, SJ2.2
PWM: IC1.6 ((PCINT7/ICP/OC0B/ADC7)PA7), IC2.1 (1-2EN), IC2.9 (3-4EN)
RESET: IC1.4 ((PCINT11/RESET/DW)PB3), PAD5.1
SCL: IC1.9 ((PCINT4/T1/SCL/USCK/ADC4)PA4), PAD7.1, SV2.3, SV3.3
SDA: IC1.7 ((PCINT6/OC1A/SDA/MOSI/ADC6)PA6), PAD1.1, SV2.4, SV3.4
U3.3: IC1.1 (VCC), IC2.16 (VCC1), PAD2.1, SJ2.3, SJ4.3, SV3.1
U5: D3.C, D4.C, D7.C, D8.C, IC2.8 (VCC2), PAD4.1, SJ2.1
U_CHARGE: JP1.2, PAD6.1



Board: 2 copper layers, 14.0 x 52.7 mm, 27 parts (11 on the bottom side), 23 nets.

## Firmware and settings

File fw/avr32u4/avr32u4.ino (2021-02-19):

#include <avr/sleep.h>
#include <Zumo32U4.h>
#include <Wire.h>
#include <avr/wdt.h>

#define CMD_BEEP                0x01
#define CMD_BATLEVEL            0x02
#define CMD_MOTORS_SET_SPEED    0x03
#define CMD_ENCODERS            0x04
#define CMD_LIDAR_SET_PWM       0x05
#define CMD_GET_STATUS          0x06
#define CMD_SET_LED             0x07
#define CMD_PUTCHAR             0x08
#define CMD_WATCHDOG            0x09

#undef ENABLE_WDT
#define ENABLE_SLEEP
#define ENABLE_LINE_SENSOR
#define ENABLE_PROX_SENSOR
Zumo32U4ButtonA           buttonA;
Zumo32U4ButtonB           buttonB;
Zumo32U4ButtonC           buttonC;
Zumo32U4Buzzer            buzzer;
Zumo32U4Motors            motors;
Zumo32U4Encoders          encoders;
#ifdef ENABLE_LINE_SENSOR
Zumo32U4LineSensors       lineSensors;
#endif
#ifdef ENABLE_PROX_SENSOR
Zumo32U4ProximitySensors  proxSensors;
#endif
#define NUM_SENSORS 5
uint16_t lineSensorValues[NUM_SENSORS];
bool useEmitters = true;

uint8_t proxSensorsValues[6] = {0};

volatile uint32_t loopcnt = 0;

volatile uint16_t bat = 0;

volatile int16_t enc_l = 0;
volatile int16_t enc_r = 0;

uint16_t buzzer_freq = 0;
uint16_t buzzer_duration = 0;
uint8_t buzzer_volume = 0;

uint8_t enable_prox_sensor = 0;
uint8_t enable_line_sensor = 0;

int16_t motor_l_speed = 0;
int16_t motor_r_speed = 0;
uint8_t motor_speed_flag = 0;

void setPwmDutyA(int val) {
  TC4H = val >> 8;
  OCR4A = 0xFF & val;
}

#if 0
uint8_t xxx = 0;
ISR(WDT_vect)
{
  if(xxx == 0 )
  {
    xxx = 1;
    ledYellow(1);
  }
  else
  {
    xxx = 0;
    ledYellow(0);
  }
}
#endif

#if 0
ISR(TIMER0_COMPA_vect) 
{
  xxx++;
  if(xxx < 128 )
  {
    ledYellow(1);
  }
  else
  {
    ledYellow(0);
  }
}
#endif

void setup()
{
  ledGreen(0);  
  Serial.begin(115200);
  Serial1.begin(115200);
  Serial.write("ZUMO: starting ...\n");
  pinMode(13, OUTPUT);
  digitalWrite(13, 0);

  motors.setLeftSpeed(0);
  motors.setRightSpeed(0);

#ifdef ENABLE_SENSORS
  lineSensors.initFiveSensors();
#endif

  //buzzer.playFrequency(55, 250, 8);
  //while (buzzer.isPlaying());

#ifdef USE_RPISLAVELIB
#else
  Wire.begin(8);                // join i2c bus with address #8
  Wire.onRequest(requestEvent); // register event
  Wire.onReceive(receiveEvent); // register event
#endif

#if 1
  PLLFRQ = (PLLFRQ & 0xCF) | 0x30;
#else
// Configure PLL.
  PLLCSR  = (1 << PINDIV);  // set if using 16MHz clock.
  PLLFRQ  = (1 << PLLUSB);  // divide PLL output by two.
  PLLFRQ |= (1 << PLLTM0);  // postscale by 1.
  PLLFRQ |= (10 << PDIV0);  // 96MHz output frequency.

  // Enable PLL.
  PLLCSR |= (1 << PLLE);    // enable PLL.
  
  // Wait for PLL lock.
  while (!(PLLCSR & (1 << PLOCK)));
#endif  

#if 1
  // 10-bit operation
  TC4H = 0x03; OCR4C = 0xFF;
  //Configuration of Timer 4 Registers, OC4A (D13) + 0C4B (D10)
  TCCR4A = (TCCR4A & 0x00111100) | 0b10000010;
  //Prescaler
  TCCR4B = (TCCR4B & 0b1110000) | 1;

  setPwmDutyA(0);
#endif

#ifdef ENABLE_LINE_SENSOR
  lineSensors.initThreeSensors();
  lineSensors.emittersOff();
#endif
#ifdef ENABLE_PROX_SENSOR
  proxSensors.pullupsOn();
  proxSensors.initThreeSensors();
  proxSensors.lineSensorEmittersOff();
#endif  
  //buzzer.playFrequency(1000, 50, 10);

  //buzzer.playFrequency(220, 50, 100);
  //while (buzzer.isPlaying());

  Serial.write("ZUMO: starting ... done\n");
  ledGreen(0);  
#ifdef ENABLE_WDT
  wdt_enable(WDTO_2S);
#endif
#if 0
    // setup of the WDT
    MCUSR &= ~(1 << WDRF); // remove reset flag
    WDTCSR |= (1 << WDCE) | (1 << WDE); // set WDCE, access prescaler
    WDTCSR = 1 << WDP0 | 1 << WDP1 | 1 << WDP2; // set prescaler bits to to 2s
    WDTCSR |= 1 << WDIE; // access WDT interrupt
#endif  

  //TIMSK0 |= _BV(OCIE0A);
  
  buzzer_freq = 440;
  buzzer_duration = 250;
  buzzer_volume = 10;
}

void loop()
{
  //ledRed((millis()%1000)<500);
  int16_t tmp_l = encoders.getCountsAndResetLeft();
  int16_t tmp_r = encoders.getCountsAndResetRight();
  uint16_t tmp_bat = readBatteryMillivolts();

  if( motor_speed_flag != 0 )
  {
    motor_speed_flag = 0;
    motors.setLeftSpeed(motor_l_speed);
    motors.setRightSpeed(motor_r_speed);
  }

#ifdef ENABLE_LINE_SENSOR
  if( enable_line_sensor == 1 )
  {
    lineSensors.read(lineSensorValues, useEmitters ? QTR_EMITTERS_ON : QTR_EMITTERS_OFF);
  }
  else
  {
    lineSensors.emittersOff();
  }
#endif
#ifdef ENABLE_PROX_SENSOR
  if( enable_prox_sensor == 1 )
  {
    proxSensors.read();
    proxSensorsValues[0] = proxSensors.countsLeftWithLeftLeds();
    proxSensorsValues[1] = proxSensors.countsLeftWithRightLeds();
    proxSensorsValues[2] = proxSensors.countsFrontWithLeftLeds();
    proxSensorsValues[3] = proxSensors.countsFrontWithRightLeds();
    proxSensorsValues[4] = proxSensors.countsRightWithLeftLeds();
    proxSensorsValues[5] = proxSensors.countsRightWithRightLeds();
  }
  else
  {
    proxSensors.lineSensorEmittersOff();    
  }
#endif
  cli();
  loopcnt++;
  bat = tmp_bat;
  enc_l += tmp_l;
  enc_r += tmp_r;
  sei();

  if( buzzer_freq != 0 )
  {
      buzzer.playFrequency(buzzer_freq, buzzer_duration, buzzer_volume);
      while (buzzer.isPlaying())
      {
         wdt_reset();
      }
      buzzer_freq = 0;
  }


#if 0
  // read from port 1, send to port 0:
  if (Serial1.available()) {
    int inByte = Serial1.read();
    Serial.write(inByte);
  }

  // read from port 0, send to port 1:
  if (Serial.available()) {
    int inByte = Serial.read();
    Serial1.write(inByte);
  }
#endif

#if 0
  if (buttonC.isPressed())
  {
    ledRed(1);
    while(1); 
  }
#endif  
  
#if 1
  ledRed(0);  
#ifdef ENABLE_SLEEP
  set_sleep_mode(SLEEP_MODE_PWR_SAVE);
#else
  set_sleep_mode(SLEEP_MODE_IDLE);
#endif  
  sleep_enable();
  sleep_mode();
  /** Das Programm läuft ab hier nach dem Aufwachen weiter. **/
  /** Es wird immer zuerst der Schlafmodus disabled.        **/
  sleep_disable();
  ledRed(1);  
#endif

#ifdef ENABLE_WDT
 wdt_reset();
#endif
}

#define MSG_UINT8(_p_)  (uint8_t)((((_p_)[1])<<0))
#define MSG_UINT16(_p_) (uint16_t)(((uint16_t)((_p_)[0])<<8)|((uint16_t)((_p_)[1])<<0))
#define MSG_UINT32(_p_) (uint32_t)(((uint32_t)((_p_)[0])<<24)|((uint32_t)((_p_)[1])<<16)|((uint32_t)((_p_)[2])<<8)|((uint32_t)((_p_)[3])<<0))

#define MSG_INT8(_p_)  (int8_t)((((_p_)[1])<<0))
#define MSG_INT16(_p_) (int16_t)(((int16_t)((_p_)[0])<<8)|((int16_t)((_p_)[1])<<0))
#define MSG_INT32(_p_) (int32_t)(((int32_t)((_p_)[0])<<24)|((int32_t)((_p_)[1])<<16)|((int32_t)((_p_)[2])<<8)|((int32_t)((_p_)[3])<<0))

uint8_t cmd = 0;

// function that executes whenever data is received from master
// this function is registered as an event, see setup()
void receiveEvent(int howMany)
{
  ledGreen(1);
  cmd = Wire.read();
  howMany--;
  if ( howMany > 0 )
  {
    const int L = 32;
    int n = 0;
    uint8_t msg[L];

    while (1 < Wire.available() && ((n + 1) < L))
    {
      // loop through all but the last
      msg[n++] = Wire.read(); // receive byte as a character
    }
    msg[n++] = Wire.read();    // receive byte as an integer

    switch (cmd)
    {
      case CMD_BEEP:
        if ( n >= (2 + 2 + 1) )
        {
          buzzer_freq = MSG_UINT16(&msg[0]);
          buzzer_duration = MSG_UINT16(&msg[2]);
          buzzer_volume = MSG_UINT8(&msg[2 + 2]);
        }
        break;
      case CMD_MOTORS_SET_SPEED:
        {
          if ( n >= (2 + 2) )
          {
            motor_l_speed = MSG_INT16(&msg[0]);
            motor_r_speed = MSG_INT16(&msg[2]);
            motor_speed_flag = 1;
          }
        }
        break;
      case CMD_LIDAR_SET_PWM:
        {
          uint16_t v = MSG_UINT16(&msg[0]);
          setPwmDutyA(v);
        }
        break;
      case CMD_SET_LED:
        {
            ledRed((MSG_UINT8(&msg[0])>>0)&1);
            ledYellow((MSG_UINT8(&msg[0])>>1)&1);
            ledGreen((MSG_UINT8(&msg[0])>>2)&1);

            enable_prox_sensor = ((MSG_UINT8(&msg[0])>>4)&1);
            enable_line_sensor = ((MSG_UINT8(&msg[0])>>5)&1);
        }
        break;
      case CMD_PUTCHAR:
        {
          int k=0;          
          for(k=0;k<n;k++)
          {
            Serial1.write(MSG_UINT8(&msg[k]));
          }
        }
        break;      
      case CMD_WATCHDOG:
        {
          if( msg[0] == 1 )
          {
            wdt_enable(WDTO_500MS);
          }
          else if( msg[0] == 2 )
          {
            wdt_enable(WDTO_1S);
          }
          else if( msg[0] == 3 )
          {
            wdt_enable(WDTO_2S);
          }
          else if( msg[0] == 4 )
          {
            wdt_enable(WDTO_4S);
          }
          else if( msg[0] == 5 )
          {
            wdt_enable(WDTO_8S);
          }
          else if( msg[0] == 6 )
          {
            wdt_disable();
          }
          else if( msg[0] == 7 )
          {
            wdt_reset();
          }
        }
        break;               
    }
  }
  ledGreen(0);
}

void requestEvent()
{
  ledGreen(1);
  uint8_t idx = 0;
  uint8_t buf[4 + 2 + 4 + 2*NUM_SENSORS + 6 + 1];

  buf[idx++] = (uint8_t)(loopcnt >> 24) & 0xff;
  buf[idx++] = (uint8_t)(loopcnt >> 16) & 0xff;
  buf[idx++] = (uint8_t)(loopcnt >> 8) & 0xff;
  buf[idx++] = (uint8_t)(loopcnt >> 0) & 0xff;

  buf[idx++] = (uint8_t)(bat >> 8) & 0xff;
  buf[idx++] = (uint8_t)(bat >> 0) & 0xff;

  buf[idx++] = (uint8_t)(enc_l >> 8) & 0xff;
  buf[idx++] = (uint8_t)(enc_l >> 0) & 0xff;
  enc_l = 0;

  buf[idx++] = (uint8_t)(enc_r >> 8) & 0xff;
  buf[idx++] = (uint8_t)(enc_r >> 0) & 0xff;
  enc_r = 0;

  {
    int i;
    for(i=0;i<NUM_SENSORS;i++)    
    {
      buf[idx++] = (uint8_t)(lineSensorValues[i] >> 8) & 0xff;
      buf[idx++] = (uint8_t)(lineSensorValues[i] >> 0) & 0xff;
    }
  }

  {
    int i = 0;
    buf[idx++] = proxSensorsValues[i++];
    buf[idx++] = proxSensorsValues[i++];
    buf[idx++] = proxSensorsValues[i++];
    buf[idx++] = proxSensorsValues[i++];
    buf[idx++] = proxSensorsValues[i++];
    buf[idx++] = proxSensorsValues[i++];
  }

  buf[idx++] = (usbPowerPresent()?(1<<4):0)|
               (buttonA.isPressed()?(1<<0):0)|
               (buttonB.isPressed()?(1<<1):0)|
               (buttonC.isPressed()?(1<<2):0);

  Wire.write(buf, sizeof(buf));
  ledGreen(0);
}

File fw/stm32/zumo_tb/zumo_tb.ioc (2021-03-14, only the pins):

PC12.Signal=GPIO_Input
PB14.GPIO_Label=I_BUS_FON
PC6.GPIO_Label=O_L_RST_9
PA6.GPIO_Label=RPI_CS0
PB6.GPIO_Label=O_L_RST_6
PB13.Signal=GPIO_Output
PD6.GPIO_Label=O_FLASH_WP
PD4.Signal=GPIO_Output
PB6.Signal=GPIO_Output
PC7.Signal=GPIO_Output
PC3.Signal=SPI2_MOSI
PD0.Signal=S_TIM16_CH1
PD8.Signal=GPIO_Output
PB2.Signal=USART3_TX
PD1.GPIO_Label=O_BUS_RESET
PB12.GPIO_Label=O_L_RST_10
PC4.GPIO_Label=U1_ESP_RXD
PB1.GPIO_Label=O_L_RST_1
PA8.Signal=GPIO_Output
PA0.Signal=ADC1_IN0
PB9.Signal=SPI2_NSS
PB1.Signal=GPIO_Output
PA10.Signal=I2C1_SDA
PA4.GPIO_Label=O_L_RST_10
PD9.GPIO_Label=O_FLASH_CS
PC13.Signal=GPIO_Input
PD3.Signal=GPIO_Output
PC6.Signal=GPIO_Output
PC2.Signal=SPI2_MISO
PD1.Signal=GPIO_Output
PC0.Signal=GPIO_Output
PA8.GPIO_Label=O_CHARGE_ON
PA9.Signal=I2C1_SCL
PB10.Signal=I2C2_SCL
PB14.Signal=GPIO_Input
PA5.Signal=SPI1_SCK
PB4.GPIO_Label=O_L_RST_4
PB15.GPIO_Label=ZUMO_SHDN
PA1.GPIO_Label=ADC1
PC7.GPIO_Label=O_L_RST_8
PA4.Signal=GPIO_Output
PB5.Signal=GPIO_Output
PA5.GPIO_Label=SPI_CLK
PC12.GPIO_Label=RPI_15
PD2.Signal=GPIO_Output
PB0.Signal=USART3_RX
PC1.Signal=GPIO_Output
PD2.GPIO_Label=O_BNO055_RESET
Mcu.UserName=STM32G081RBTx
PC10.Signal=GPIO_Input
PA0.GPIO_Label=ADC0
PD0.GPIO_Label=O_LIDAR_M
PC0.GPIO_Label=O_CAM_PWDN
PB0.GPIO_Label=U3_ZUMO_TXD
PC13.GPIO_Label=RPI_16
PB13.GPIO_Label=O_L_RST_11
PB11.Signal=LPUART1_TX
PB15.Signal=GPIO_Input
PA15.GPIO_Label=SPI_CS
PA14-BOOT0.Signal=SYS_SWCLK
PC11.GPIO_Label=RPI_14
PB7.Signal=GPIO_Output
PB7.GPIO_Label=O_L_RST_7
PA6.Signal=GPIO_Input
PD5.GPIO_Label=O_FLASH_HOLD
PA2.GPIO_Label=O_LED2
PA15.Signal=SPI1_NSS
PB5.GPIO_Label=O_L_RST_5
PC5.Signal=USART1_RX
PD3.GPIO_Label=O_L_RST_0
PD6.Signal=GPIO_Output
PB4.Signal=GPIO_Output
PA3.Signal=LPUART1_RX
PB3.GPIO_Label=O_L_RST_3
PC10.GPIO_Label=RPI_13
PC9.GPIO_Label=RPI_12
PC11.Signal=GPIO_Input
PC8.Signal=GPIO_Input
PC4.Signal=USART1_TX
PD5.Signal=GPIO_Output
PD9.Signal=GPIO_Output
PD8.GPIO_Label=O_LEDSTRB
PC8.GPIO_Label=RPI_11
PA13.Signal=SYS_SWDIO
PB10.GPIO_Label=SCL2
PA1.Signal=ADC1_IN1
PD4.GPIO_Label=O_L_RST_2
PC1.GPIO_Label=O_LED1
PA2.Signal=GPIO_Output
PB3.Signal=GPIO_Output
PA7.GPIO_Label=RPI_CS1
PC5.GPIO_Label=U1_ESP_TXD
PB2.GPIO_Label=U3_ZUMO_RXD
PB8.Signal=SPI2_SCK
PC9.Signal=GPIO_Input
PB12.Signal=GPIO_Output
PA7.Signal=GPIO_Input

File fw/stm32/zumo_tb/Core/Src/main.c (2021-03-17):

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
/* Includes ------------------------------------------------------------------*/
#include "main.h"
#include "adc.h"
#include "dma.h"
#include "i2c.h"
#include "iwdg.h"
#include "lptim.h"
#include "usart.h"
#include "rtc.h"
#include "spi.h"
#include "tim.h"
#include "gpio.h"

/* USER CODE BEGIN Includes */

#include "config.h"
#include "stm32g0xx_hal_pwr_ex.h"
#ifdef ENABLE_LCD_UI
#include "ui.h"
#endif
#include "pm.h"

/* USER CODE END Includes */

/* USER CODE BEGIN PTD */

//#define ENABLE_SEMI_PRINTF

/* USER CODE END PTD */


void SystemClock_Config(void);
/* USER CODE BEGIN PFP */
void FastSystemClock_Config(void);
uint8_t sysfastclock = 0;
extern void initialise_monitor_handles(void);
void vUpdateRSTGPIOs();
void vUpdateRPIGPIOs();

/* USER CODE END PFP */

/* USER CODE BEGIN 0 */

/* Buffer used for reception */
uint8_t lds_previdx = 0;
uint8_t ldx_rxbuf[8];
uint8_t lds_frmidx = 0;
uint8_t lds_frm[22];
#define LDS_POINTS 360
struct
{
	uint8_t index;
	uint8_t data[4];
} lds_data[LDS_POINTS];
struct
{
	uint8_t index;
	uint8_t data[4];
} lds_data_bak[LDS_POINTS];
uint16_t lds_data_bak_cnt = 0;
struct
{
	uint8_t index;
	uint8_t data[4];
} lds_data_i2c[LDS_POINTS];
uint16_t lds_data_i2c_cnt = 0;
uint16_t lds_data_i2c_addr = 0;

/**
  * @brief  Rx Transfer completed callback
  * @param  UartHandle: UART handle
  * @note   This example shows a simple way to report end of DMA Rx transfer, and
  *         you can add your own implementation.
  * @retval None
  */
void HAL_UART_RxCpltCallback(UART_HandleTypeDef *huart) {
	/*
	22 Bytes: <start> <index> <speed_L> <speed_H> [Data 0] [Data 1] [Data 2] [Data 3] <checksum_L> <checksum_H>

	start is always 0xFA
	index is the index byte in the 90 packets, going from 0xA0 (packet 0, readings 0 to 3) to 0xF9 (packet 89, readings 356 to 359).
	speed is a two-byte information, little-endian. It represents the speed, in 64th of RPM (aka value in RPM represented in fixed point, with 6 bits used for the decimal part).
	[Data 0] to [Data 3] are the 4 readings. Each one is 4 bytes long, and organized as follows :

	`byte 0 : <distance 7:0>`
	`byte 1 : <„invalid data“ flag> <„strength warning“ flag> <distance 13:8>`
	`byte 2 : <signal strength 7:0>`
	`byte 3 : <signal strength 15:8>`
	 */

	int j;
	for(j=0;j<sizeof(ldx_rxbuf);j++)
	{
		lds_frm[lds_frmidx] = ldx_rxbuf[j];
		if( lds_frm[0] == 0xFA )
		{
			lds_frmidx++;
			lds_previdx = 0xA0-1;
		}
		if( lds_frmidx == 22 )
		{
			uint32_t chk32 = 0;
			int i;
			for(i=0; i<10; i++)
			{
			    chk32 = (chk32 << 1) + (lds_frm[2*i+0]|lds_frm[2*i+1]<<8);
			}
			chk32 = (chk32 & 0x7FFF) + (chk32 >> 15);
			chk32 &= 0x7FFF;
			if( ((chk32>>0)&0xff) == lds_frm[20] && ((chk32>>8)&0xff) == lds_frm[21] )
			{
				uint8_t index = lds_frm[1];
				double speed = (lds_frm[2] | lds_frm[3]<<8)/64.0;
				struct
				{
					uint8_t  distance;
					uint8_t  invalid;
					uint8_t  strength_warning;
					int16_t  signal;
				} data[4];
				int rpm = API_I2C1_u8Get(I2C_REG_TB_U8_LDS_SPEED) * 60;
				if( rpm != 0 )
				{
					if( speed < rpm )
					{
						if( htim16.Instance->CCR1 < 10000 )
							htim16.Instance->CCR1++;
					}
					else if( speed > rpm )
					{
						if( htim16.Instance->CCR1 > 1000 )
							htim16.Instance->CCR1--;
					}
				}
				if( lds_previdx+1 == index )
				{
					for(i=0;i<4;i++)
					{
						data[i].distance = (lds_frm[4+4*i+0] | (lds_frm[4+4*i+1]<<8))&0x3fff;
						data[i].invalid = (lds_frm[4+4*i+1]>>7)&1;
						data[i].strength_warning = (lds_frm[4+4*i+1]>>6)&1;
						data[i].signal = lds_frm[4+4*i+2] + (lds_frm[4+4*i+3]<<8);

						int p = (4*(index-0xA0) + i);
						if(p>=0 && p<LDS_POINTS )
						{
							lds_data[p].index = index;
							lds_data[p].data[0] = lds_frm[4+4*i+0];
							lds_data[p].data[1] = lds_frm[4+4*i+1];
							lds_data[p].data[2] = lds_frm[4+4*i+2];
							lds_data[p].data[3] = lds_frm[4+4*i+3];
							if( p==((LDS_POINTS)-1) )
							{
								memcpy(&lds_data_bak,&lds_data,sizeof(lds_data_bak));
								lds_data_bak_cnt++;
								if( (API_I2C1_u8Get(I2C_REG_TB_U8_INT_ENABLE)&I2C_REG_TB_U8_INT_BIT__LDS_READY) != 0 )
								{
									API_I2C1_u8Set(I2C_REG_TB_U8_INT_FLAGS,API_I2C1_u8Get(I2C_REG_TB_U8_INT_FLAGS)|I2C_REG_TB_U8_INT_BIT__LDS_READY);
								}

							}
						}
					}
				}
				else
				{
					lds_previdx = 0x00;
				}
	#ifdef ENABLE_SEMI_PRINTF
				if( index == 0xA0 )
				{
					printf("0x%02x idx=%02x speed=%3.0f pwm=%d (%d,%d,%d,%d) (%d,%d,%d,%d) (%d,%d,%d,%d) (%d,%d,%d,%d) \n",
							lds_frm[0],
							index,
							speed,htim16.Instance->CCR1,
							data[0].distance,data[0].invalid,data[0].strength_warning,data[0].signal,
							data[1].distance,data[1].invalid,data[1].strength_warning,data[1].signal,
							data[2].distance,data[2].invalid,data[2].strength_warning,data[2].signal,
							data[3].distance,data[3].invalid,data[3].strength_warning,data[3].signal);
				}
	#endif
			}
			lds_frm[0] = 0;
			lds_frmidx = 0;
			lds_previdx = 0x00;
			memset(&lds_data,0,sizeof(lds_data));
		}
	}

	if (HAL_UART_Receive_IT(&hlpuart1, (uint8_t *)ldx_rxbuf, sizeof(ldx_rxbuf)) != HAL_OK)
	{
		Error_Handler();
	}
}

/* USER CODE END 0 */

/**
  * @brief  The application entry point.
  * @retval int
  */
int main(void)
{
  /* USER CODE BEGIN 1 */
#ifdef ENABLE_SEMI_PRINTF
  initialise_monitor_handles();
#endif
  /* USER CODE END 1 */

  /* MCU Configuration--------------------------------------------------------*/

  /* Reset of all peripherals, Initializes the Flash interface and the Systick. */
  HAL_Init();

  /* Configure the system clock */
  SystemClock_Config();

  /* Initialize all configured peripherals */
  MX_GPIO_Init();
  MX_DMA_Init();
  MX_SPI1_Init();
  MX_TIM1_Init();
  MX_RTC_Init();
  MX_ADC1_Init();
  MX_TIM16_Init();
  MX_LPTIM1_Init();
  MX_IWDG_Init();
  MX_I2C1_Init();
  MX_LPUART1_UART_Init();
  /* USER CODE BEGIN 2 */

  __HAL_RCC_PWR_CLK_ENABLE();

#if 0
  /* Disable Prefetch Buffer */
  __HAL_FLASH_PREFETCH_BUFFER_DISABLE();

  RCC->IOPSMENR  = 0x00u;
  RCC->AHBSMENR  = 0x00u;

  RCC->APBSMENR1 = 0x00u;
  RCC->APBSMENR2 = 0x00u;
#endif

  pm_early_init();

#ifdef HAL_IWDG_MODULE_ENABLED
	HAL_IWDG_Refresh(&hiwdg);
#endif

#if 0
  /* Enable Power Clock */
  __HAL_RCC_PWR_CLK_ENABLE();

  /* Reduce the System clock */
  SystemClock_Decrease();

  /* Set regulator voltage to scale 2 */
  HAL_PWREx_ControlVoltageScaling(PWR_REGULATOR_VOLTAGE_SCALE2);

  /* Enter LP RUN Mode */
  HAL_PWREx_EnableLowPowerRunMode();
#endif

  //printf("main() ...\n");
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

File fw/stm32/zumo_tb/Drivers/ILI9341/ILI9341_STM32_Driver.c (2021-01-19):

//	MIT License
//
//	Copyright (c) 2017 Matej Artnak
//
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
//
//
//-----------------------------------
//	ILI9341 Driver library for STM32
//-----------------------------------
//
//	While there are other libraries for ILI9341 they mostly require either interrupts, DMA or both for fast drawing
//	The intent of this library is to offer a simple yet still reasonably fast alternatives for those that
//	do not wish to use interrupts or DMA in their projects.
//
//	Library is written for STM32 HAL library and supports STM32CUBEMX. To use the library with Cube software
//	you need to tick the box that generates peripheral initialization code in their own respective .c and .h file
//
//
//-----------------------------------
//	Performance
//-----------------------------------
//	Settings:	
//	--SPI @ 50MHz 
//	--STM32F746ZG Nucleo board
//	--Redraw entire screen
//
//	++		Theoretical maximum FPS with 50Mhz SPI calculated to be 40.69 FPS
//	++		320*240 = 76800 pixels, each pixel contains 16bit colour information (2x8)
//	++		Theoretical Max FPS: 1/((320*240*16)/50000000)
//
//	With ART Accelerator, instruction prefetch, CPI ICACHE and CPU DCACHE enabled:
//
//	-FPS:									39.62
//	-SPI utilization:			97.37%
//	-MB/Second:						6.09
//
//	With ART Accelerator, instruction prefetch, CPI ICACHE and CPU DCACHE disabled:
//
//	-FPS:									35.45
//	-SPI utilization:			87.12%
//	-MB/Second:						5.44
//	
//	ART Accelerator, instruction prefetch, CPI ICACHE and CPU DCACHE settings found in MXCUBE under "System-> CORTEX M7 button"
//
//
//
//-----------------------------------
//	How to use this library
//-----------------------------------
//
//	-generate SPI peripheral and 3 GPIO_SPEED_FREQ_VERY_HIGH GPIO outputs
//	 		++Library reinitializes GPIOs and SPIs generated by gpio.c/.h and spi.c/.h using MX_X_Init(); calls
//			++reinitialization will not clash with previous initialization so generated initializations can be laft as they are
//	-If using MCUs other than STM32F7 you will have to change the #include "stm32f7xx_hal.h" in the ILI9341_STM32_Driver.h to your respective .h file
//	-define your HSPI_INSTANCE in ILI9341_STM32_Driver.h
//	-define your CS, DC and RST outputs in ILI9341_STM32_Driver.h
//	-check if ILI9341_SCREEN_HEIGHT and ILI9341_SCREEN_WIDTH match your LCD size
//			++Library was written and tested for 320x240 screen size. Other sizes might have issues**
//	-in your main program initialize LCD with ILI9341_Init();
//	-library is now ready to be used. Driver library has only basic functions, for more advanced functions see ILI9341_GFX library	
//
//-----------------------------------

/* Includes ------------------------------------------------------------------*/
#include "ILI9341_STM32_Driver.h"
#include "gpio.h"

/* Global Variables ------------------------------------------------------------------*/
volatile uint16_t LCD_HEIGHT = ILI9341_SCREEN_HEIGHT;
volatile uint16_t LCD_WIDTH	 = ILI9341_SCREEN_WIDTH;

/* Initialize SPI */
void ILI9341_SPI_Init(void)
{
	MX_SPI1_Init();																							//SPI INIT
	MX_GPIO_Init();																							//GPIO INIT
	HAL_GPIO_WritePin(LCD_CS_Port, LCD_CS_PIN, GPIO_PIN_RESET);	//CS OFF
}

/*Send data (char) to LCD*/
void ILI9341_SPI_Send(unsigned char SPI_Data)
{
	HAL_SPI_Transmit(HSPI_INSTANCE, &SPI_Data, 1, 1);
}

/* Send command (char) to LCD */
void ILI9341_Write_Command(uint8_t Command)
{
	HAL_GPIO_WritePin(LCD_CS_Port, LCD_CS_PIN, GPIO_PIN_RESET);
	HAL_GPIO_WritePin(LCD_DC_Port, LCD_DC_PIN, GPIO_PIN_RESET);
	ILI9341_SPI_Send(Command);
	HAL_GPIO_WritePin(LCD_CS_Port, LCD_CS_PIN, GPIO_PIN_SET);
}

/* Send Data (char) to LCD */
void ILI9341_Write_Data(uint8_t Data)
{
	HAL_GPIO_WritePin(LCD_DC_Port, LCD_DC_PIN, GPIO_PIN_SET);
	HAL_GPIO_WritePin(LCD_CS_Port, LCD_CS_PIN, GPIO_PIN_RESET);
	ILI9341_SPI_Send(Data);
	HAL_GPIO_WritePin(LCD_CS_Port, LCD_CS_PIN, GPIO_PIN_SET);
}

/* Set Address - Location block - to draw into */
void ILI9341_Set_Address(uint16_t X1, uint16_t Y1, uint16_t X2, uint16_t Y2)
{
	ILI9341_Write_Command(0x2A);
	ILI9341_Write_Data(X1>>8);
	ILI9341_Write_Data(X1);
	ILI9341_Write_Data(X2>>8);
	ILI9341_Write_Data(X2);

	ILI9341_Write_Command(0x2B);
	ILI9341_Write_Data(Y1>>8);
	ILI9341_Write_Data(Y1);
	ILI9341_Write_Data(Y2>>8);
	ILI9341_Write_Data(Y2);

	ILI9341_Write_Command(0x2C);
}

/*HARDWARE RESET*/
void ILI9341_Reset(void)
{
	HAL_GPIO_WritePin(LCD_RST_Port, LCD_RST_PIN, GPIO_PIN_RESET);
	HAL_Delay(20);
	HAL_GPIO_WritePin(LCD_CS_Port, LCD_CS_PIN, GPIO_PIN_RESET);
	HAL_Delay(20);
	HAL_GPIO_WritePin(LCD_RST_Port, LCD_RST_PIN, GPIO_PIN_SET);
}

/*Ser rotation of the screen - changes x0 and y0*/
void ILI9341_Set_Rotation(uint8_t Rotation) 
{

	uint8_t screen_rotation = Rotation;

	ILI9341_Write_Command(0x36);
	HAL_Delay(1);

	switch(screen_rotation)
	{
	case SCREEN_VERTICAL_1:
		ILI9341_Write_Data(0x40|0x08);
		LCD_WIDTH = 240;
		LCD_HEIGHT = 320;
		break;
	case SCREEN_HORIZONTAL_1:
		ILI9341_Write_Data(0x20|0x08);
		LCD_WIDTH  = 320;
		LCD_HEIGHT = 240;
		break;
	case SCREEN_VERTICAL_2:
		ILI9341_Write_Data(0x80|0x08);
		LCD_WIDTH  = 240;
		LCD_HEIGHT = 320;
		break;
	case SCREEN_HORIZONTAL_2:
		ILI9341_Write_Data(0x40|0x80|0x20|0x08);
		LCD_WIDTH  = 320;
		LCD_HEIGHT = 240;
		break;
	default:
		//EXIT IF SCREEN ROTATION NOT VALID!
		break;
	}
}

/*Enable LCD display*/
void ILI9341_Enable(void)
{
	HAL_GPIO_WritePin(LCD_RST_Port, LCD_RST_PIN, GPIO_PIN_SET);
}
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

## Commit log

2020-01-24 i2c api added
2020-04-20 i2c terminal added
2020-04-23 some optimiziations
    [zumo_tb_02.brd, zumo_tb_02.sch]
2020-09-26 stm32 firmware improved
    [zumo_tb Debug.cfg, zumo_tb_03.brd, zumo_tb_03.sch]
2020-09-27 some monification for new pcb
2020-10-01 some 3d parts added and wireless charging fixed
    [zumo_bat_cover.scad, zumo_bat_cover.stl, zumo_docking.scad]
2020-12-13 urdf added
2020-12-13 stm32 code improved
    [zumo_bat_cover.scad, zumo_bat_cover.stl]
2021-01-19 stm32 cube fw updated
2021-03-12 uart added
2021-03-13 lds pwm enabled
2021-03-13 LDS uart decoder implemented
    [zumo_tb Debug.cfg]
2021-03-14 lds support in i2c driver implemented

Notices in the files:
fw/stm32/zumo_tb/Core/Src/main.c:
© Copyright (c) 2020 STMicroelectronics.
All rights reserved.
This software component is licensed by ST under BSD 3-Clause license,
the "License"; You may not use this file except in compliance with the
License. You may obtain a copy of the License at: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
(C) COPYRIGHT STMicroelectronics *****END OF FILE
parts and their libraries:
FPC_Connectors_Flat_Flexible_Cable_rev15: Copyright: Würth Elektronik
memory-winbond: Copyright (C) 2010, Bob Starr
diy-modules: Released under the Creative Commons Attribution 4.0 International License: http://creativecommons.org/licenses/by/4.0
